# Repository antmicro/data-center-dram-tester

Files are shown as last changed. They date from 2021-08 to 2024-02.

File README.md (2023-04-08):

# Data Center RDIMM DDR4 Tester

Copyright (c) 2021-2023 [Antmicro](https://antmicro.com)



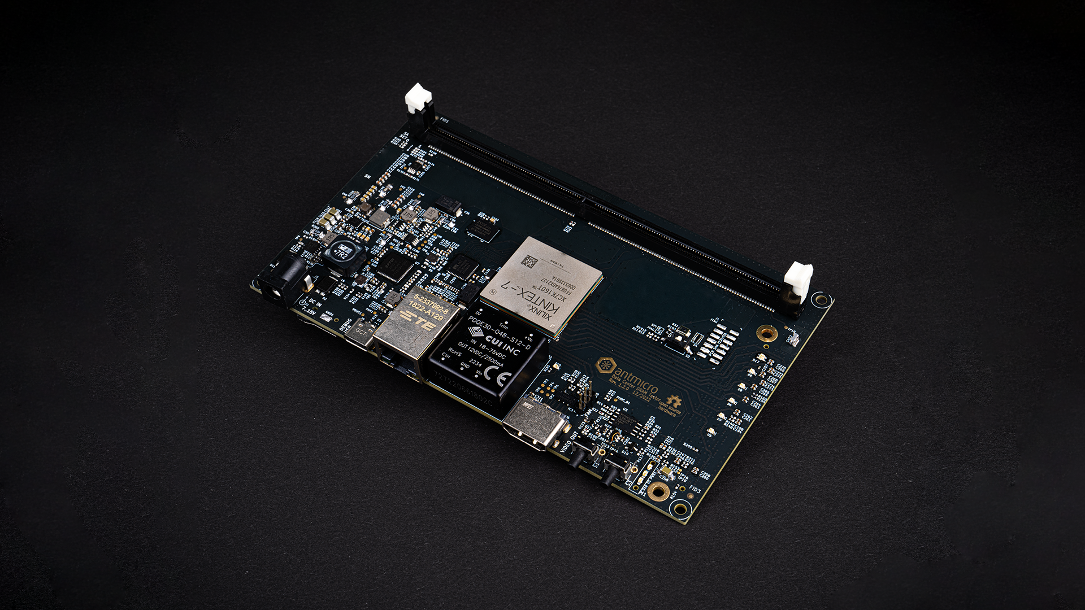
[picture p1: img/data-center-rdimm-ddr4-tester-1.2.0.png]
DDR4 RDIMM tester board


## Overview

This repository contains open hardware KiCad design files for an experimental platform built around the Xilinx Kintex-7 FPGA which can be used to interface with RDIMM DDR4 RAM modules used in data centers.

This hardware platform is used in Antmicro's and Google's [Rowhammer testing framework](https://github.com/antmicro/rowhammer-tester) which can be used to perform (and potentially mitigate) Rowhammer attacks on DRAM memories. You can learn more about Rowhammer and our work towards mitigating it in a Google Open Source blog note [describing a related platform](https://opensource.googleblog.com/2021/11/Open%20source%20DDR%20controller%20framework%20for%20mitigating%20Rowhammer.html).
The usage instructions for this board are also provided in the [Rowhammer testing framework documentation](https://antmicro.github.io/rowhammer-tester/). 

## Repository structure

The main repository directory contains KiCad PCB project files, a LICENSE and README.
The remaining files are stored in the following directories:

* `lib` - contains the component libraries
* `img` - contains graphics for this README

## Key Features

* Kintex-7 FPGA (XC7K160T-FFG676)
* DDR4 RDIMM connector with hotswap
* HDMI output connector
* Ethernet RJ45 connector with 1GbE transciever
* USB-C debug connector with FT4232HQ FTDI USB controller
* JTAG
* microSD card slot
* 16 MBytes S25FL128S QSPI FLASH memory
* S27KL0641 HyperRAM
* External 7-12V DC power input
* PoE++
* Power consumption monitoring
* 5 user LEDs
* Optional FMC HPC expansion connector

## Block diagram

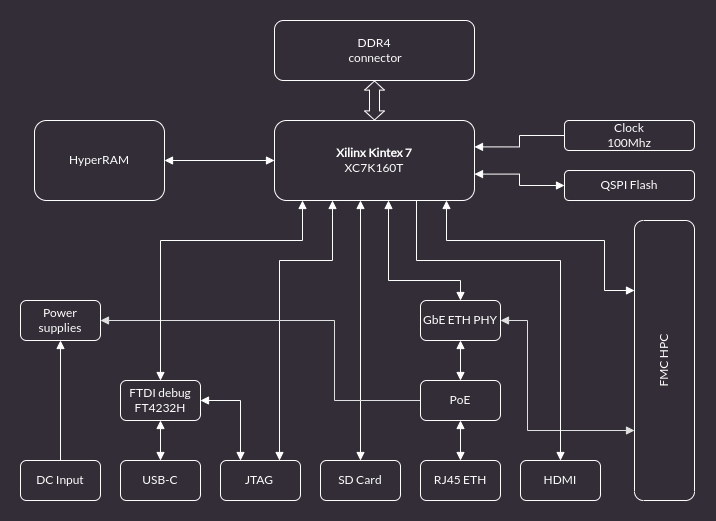
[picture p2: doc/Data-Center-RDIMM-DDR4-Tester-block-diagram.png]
Data Center RDIMM DDR4 Tester board diagram


## License

This project is published under the [Apache-2.0](LICENSE) license.

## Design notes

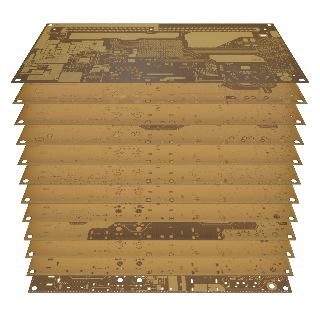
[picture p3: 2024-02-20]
assets/previews/layer1_thumbnail.webp

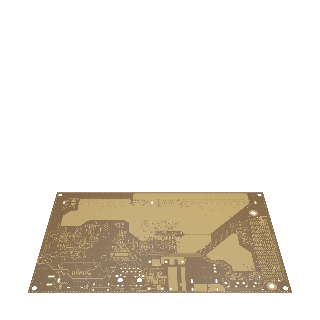
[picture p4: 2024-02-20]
assets/previews/layer12_thumbnail.png

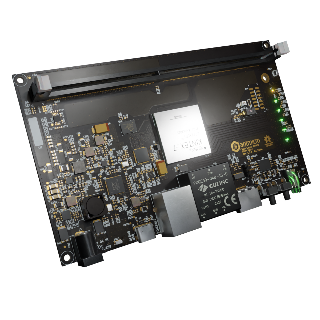
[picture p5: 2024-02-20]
assets/previews/leftT_thumbnail.png

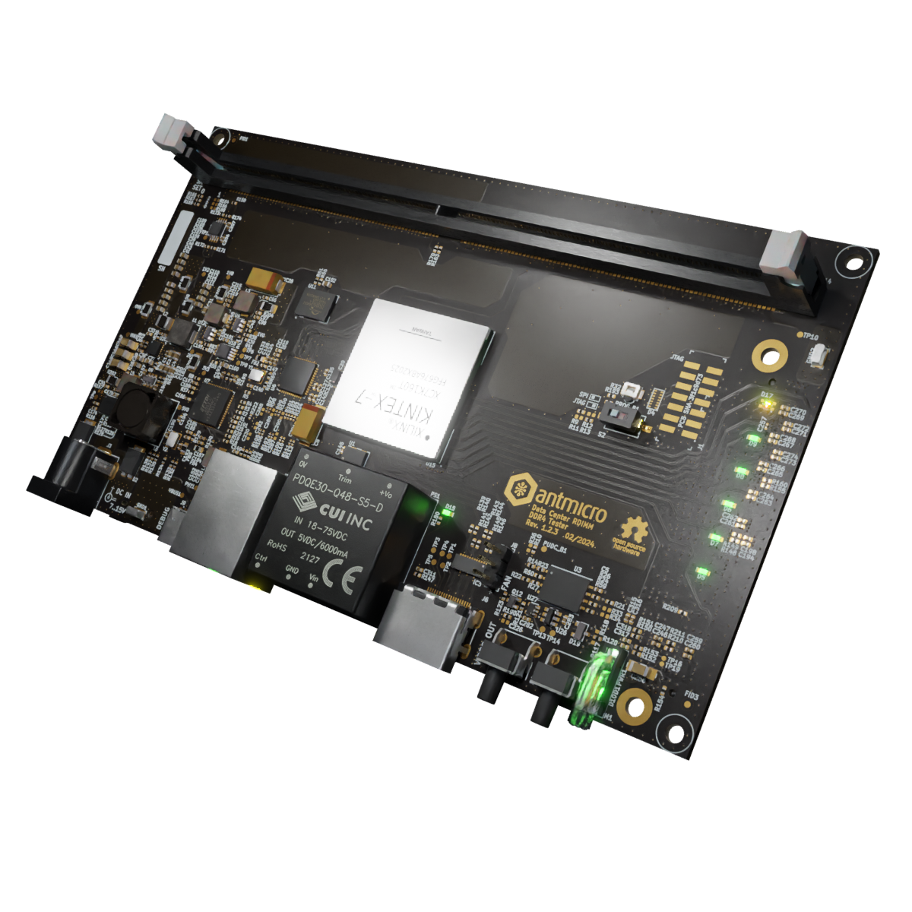
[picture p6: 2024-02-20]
assets/previews/rightT.webp

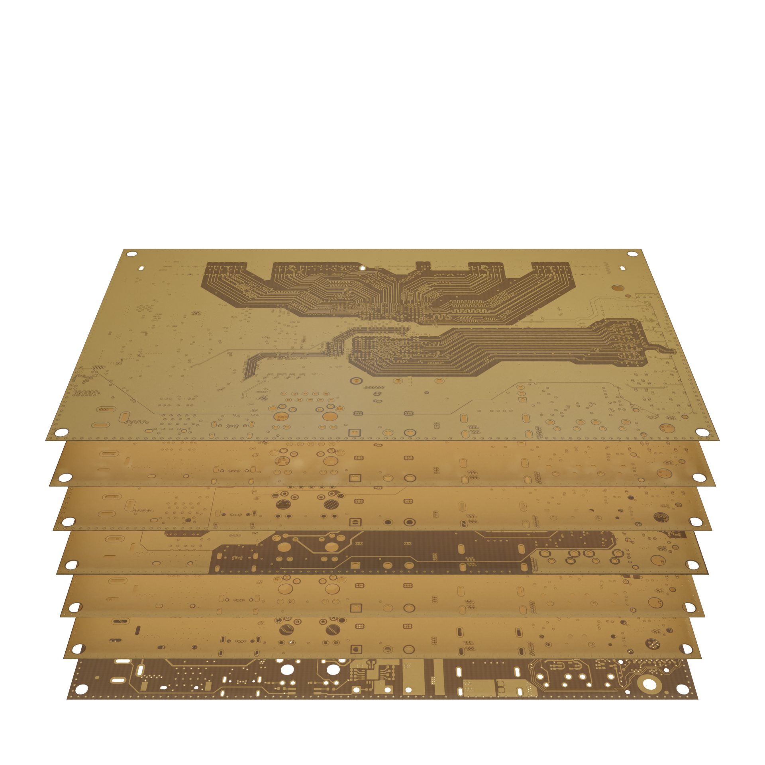
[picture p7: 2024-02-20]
assets/previews/layer6.png

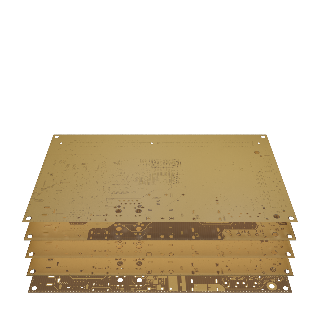
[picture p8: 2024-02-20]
assets/previews/layer8_thumbnail.png

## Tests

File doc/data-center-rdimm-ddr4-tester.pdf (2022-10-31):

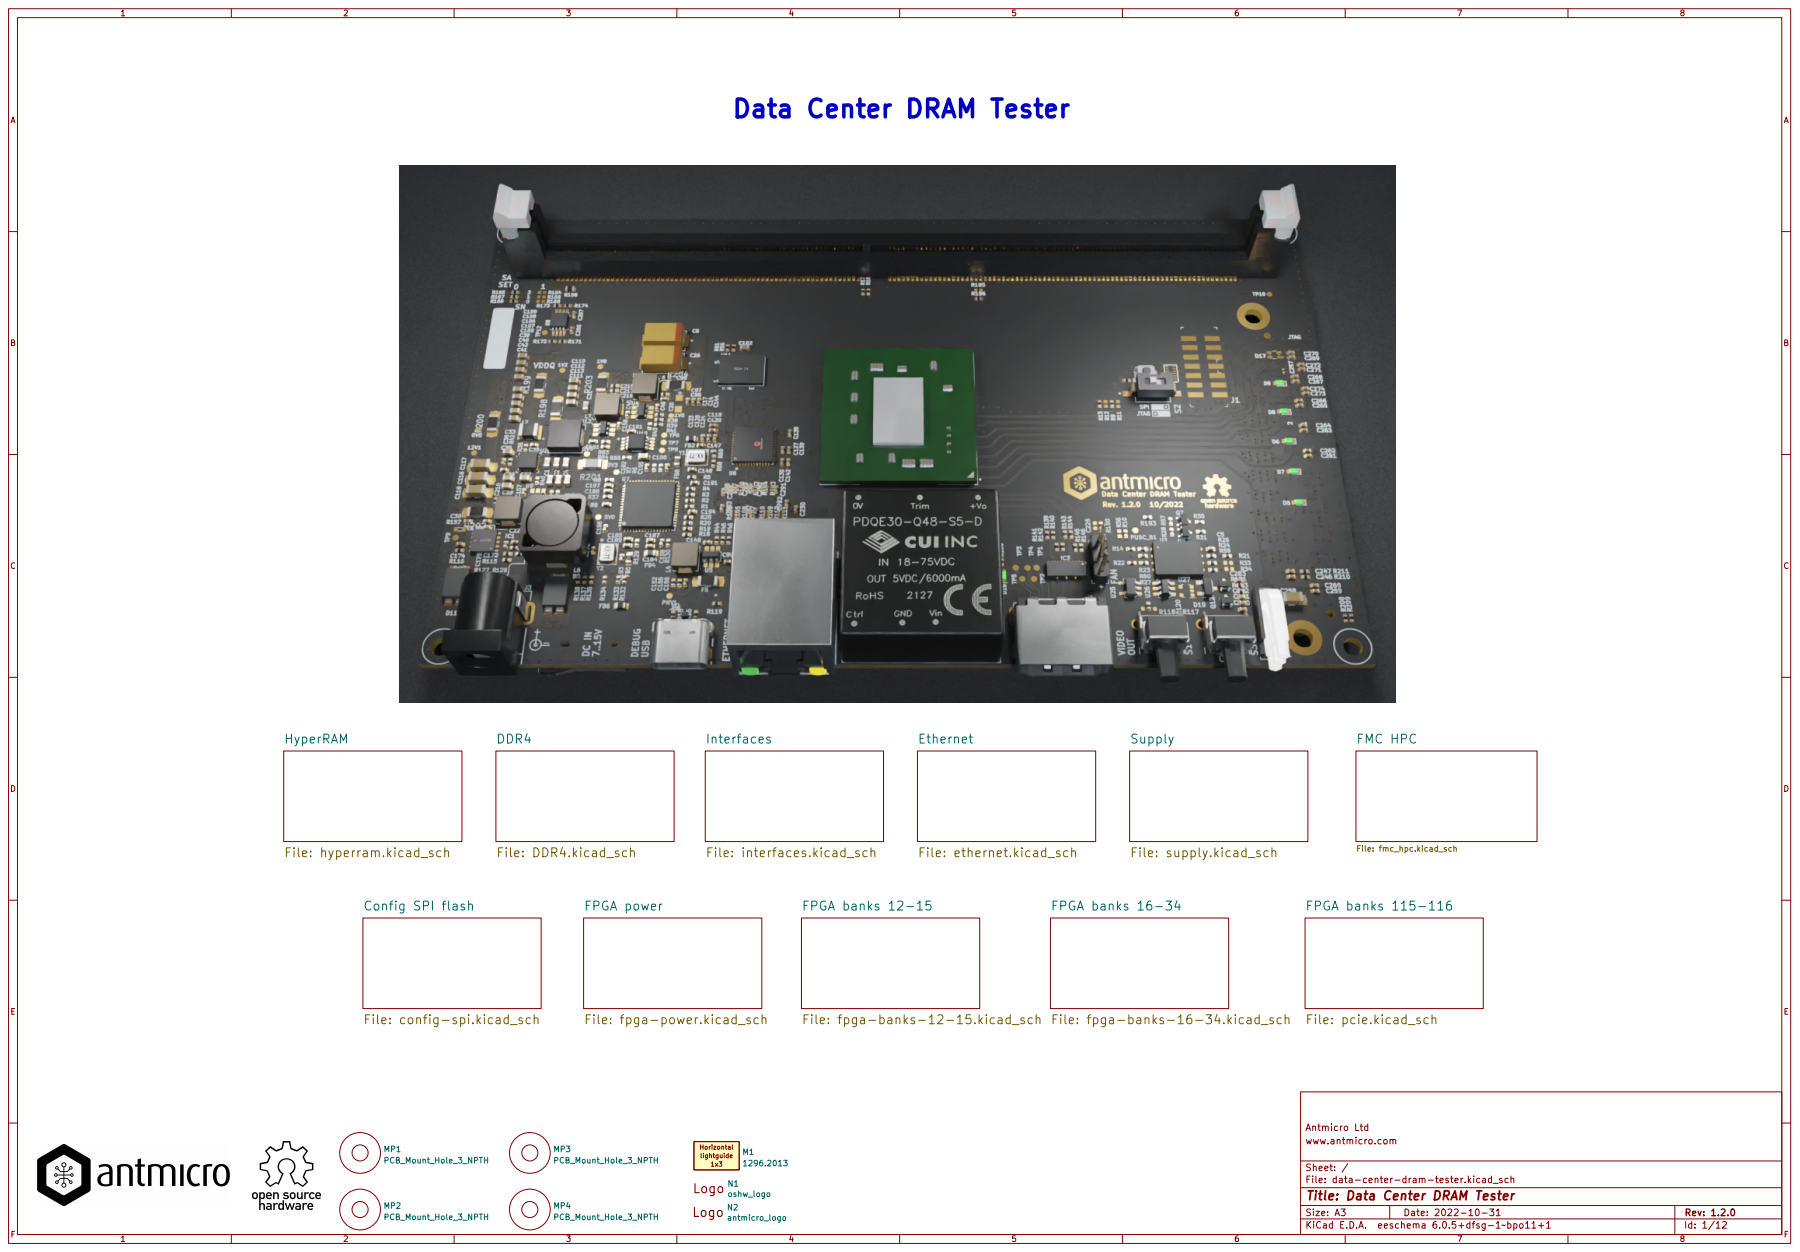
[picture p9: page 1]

File: data-center-dram-tester.kicad_sch Sheet: / www.antmicro.com

Id: 1/12 Title: Data Center DRAM Tester

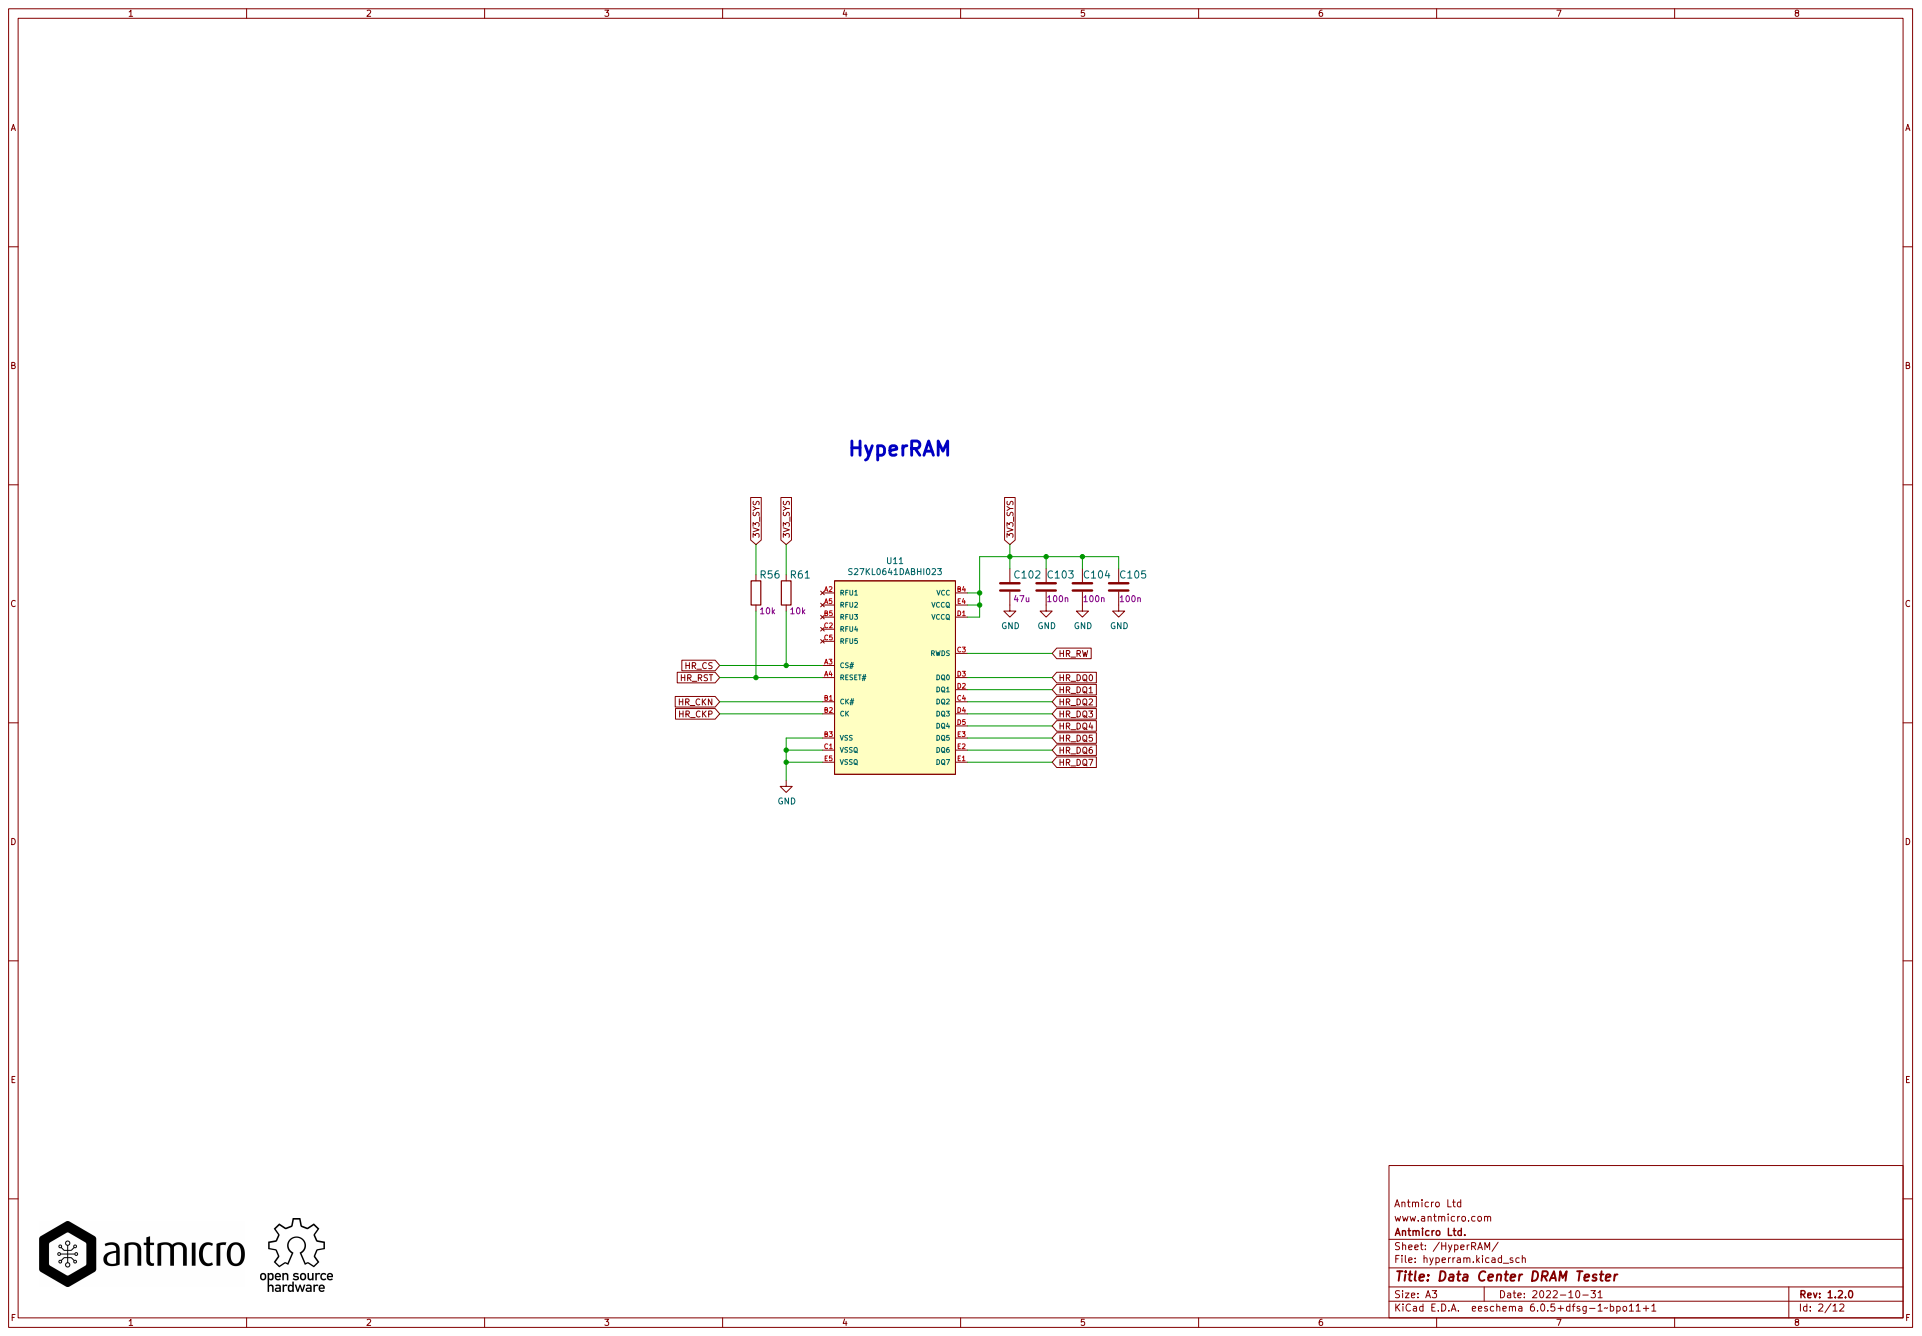
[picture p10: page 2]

Antmicro Ltd
Sheet: /HyperRAM/ Antmicro Ltd. www.antmicro.com

File: hyperram.kicad_sch
Id: 2/12 Title: Data Center DRAM Tester

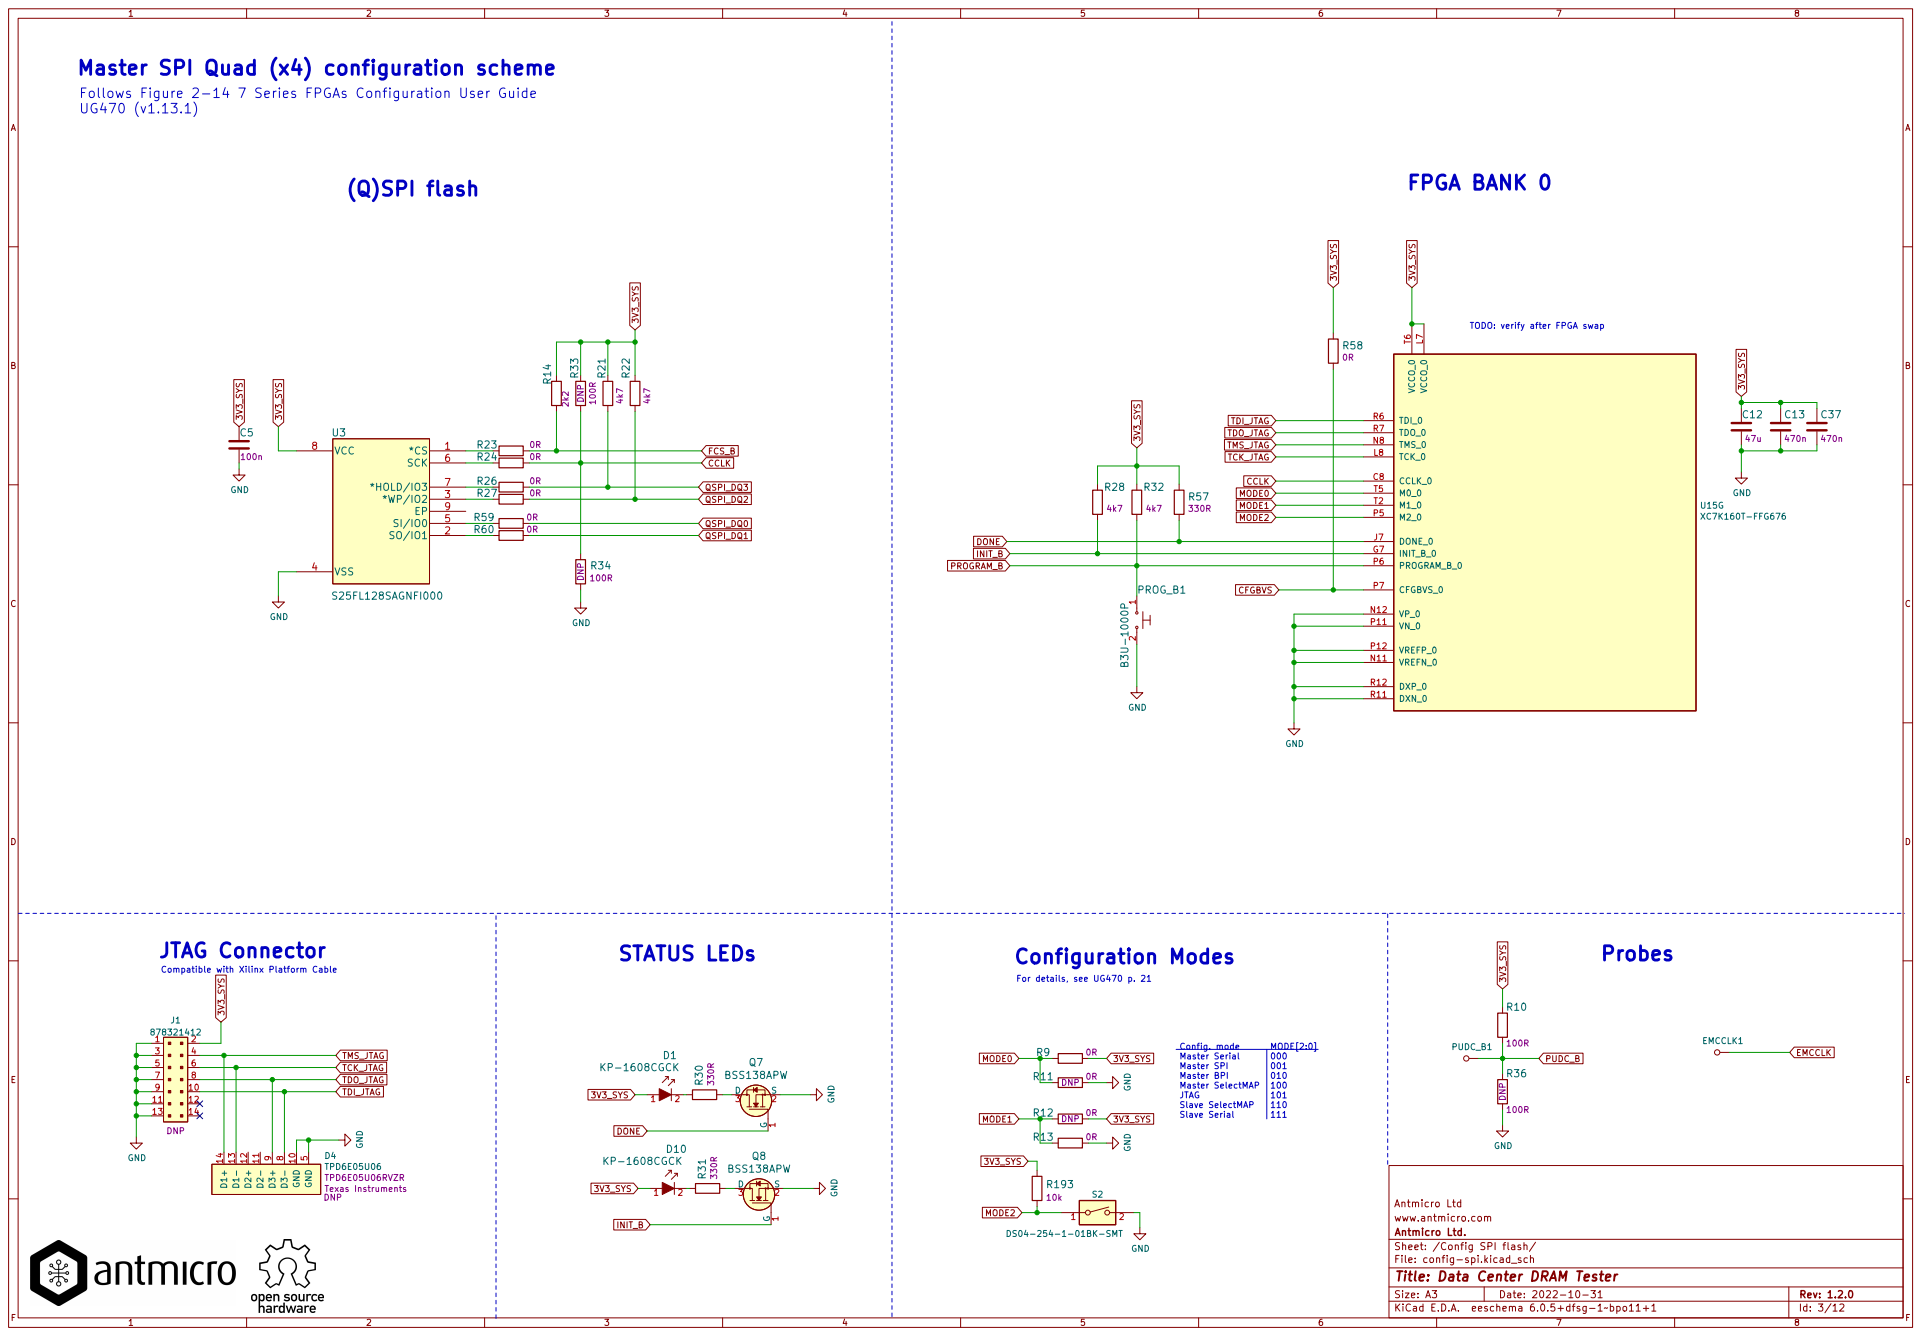
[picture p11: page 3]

Master SPI Quad (x4) configuration scheme
Follows Figure 2-14 7 Series FPGAs Configuration User Guide

TODO: verify after FPGA swap

Compatible with Xilinx Platform Cable
878321412 DNP

Config. mode Master Serial Master SPI Master BPI Master SelectMAP

9 | 10

Sheet: /Config SPI flash/ Antmicro Ltd. www.antmicro.com

File: config-spi.kicad_sch
Id: 3/12 Title: Data Center DRAM Tester

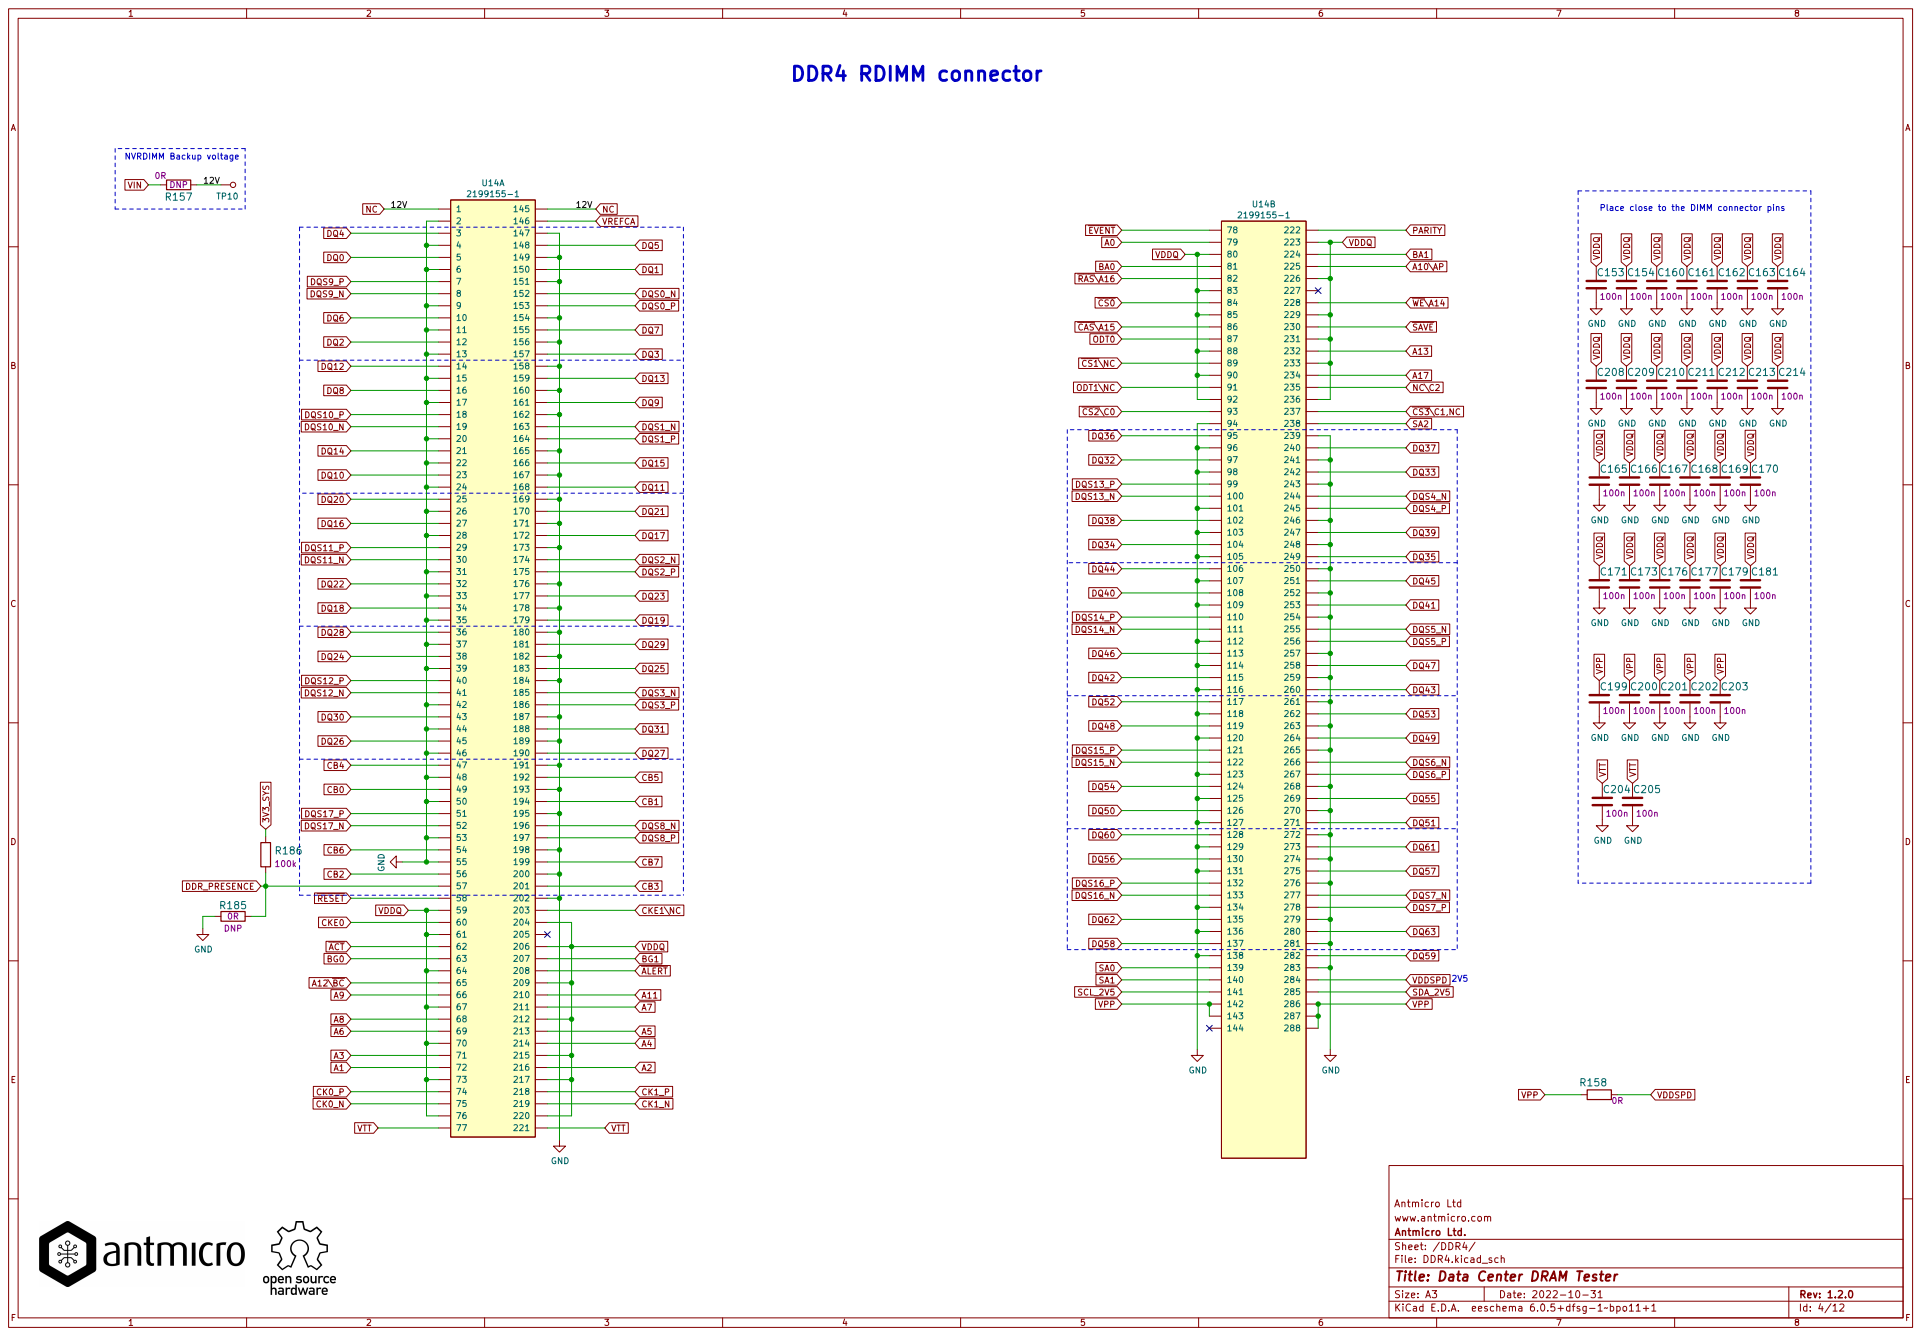
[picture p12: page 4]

DQ20 | | 7789 U14A 697 25 169 26 170 27 171 28 172 173 30 174 31 175 32 176 33 177 34 178 35 179 | DQS2_N

Place close to the DIMM connector pins

199 2 394 495 596 14 158 15 159 16 160 17 161 18 162 19 163 20 164 21 165 22 166 23 167 24 168 | DQ7 DQ5 DQS0_P DQ14 DQS8_N DQS1_N

DQS12_N | | 36 180 37 181 38 182 183 40 184 41 185 42 186 43 187 44 188 45 189 46 190 | DQS3_N

117 261 118 262 119 263 120 264 121 265 122 266 123 267 124 268 125 269 126 270 127 271 | DQ47 DQS6_P DQS6_N

128 272 129 273 130 274 131 275 132 276 133 277 134 278 135 279 136 280 137 281 | DQ61 SCL_2V5 DQS16_N DQ57 SA1 DQS7_N

Antmicro Ltd
File: DDR4.kicad_sch Sheet: /DDR4/ Antmicro Ltd. www.antmicro.com

Id: 4/12 Title: Data Center DRAM Tester

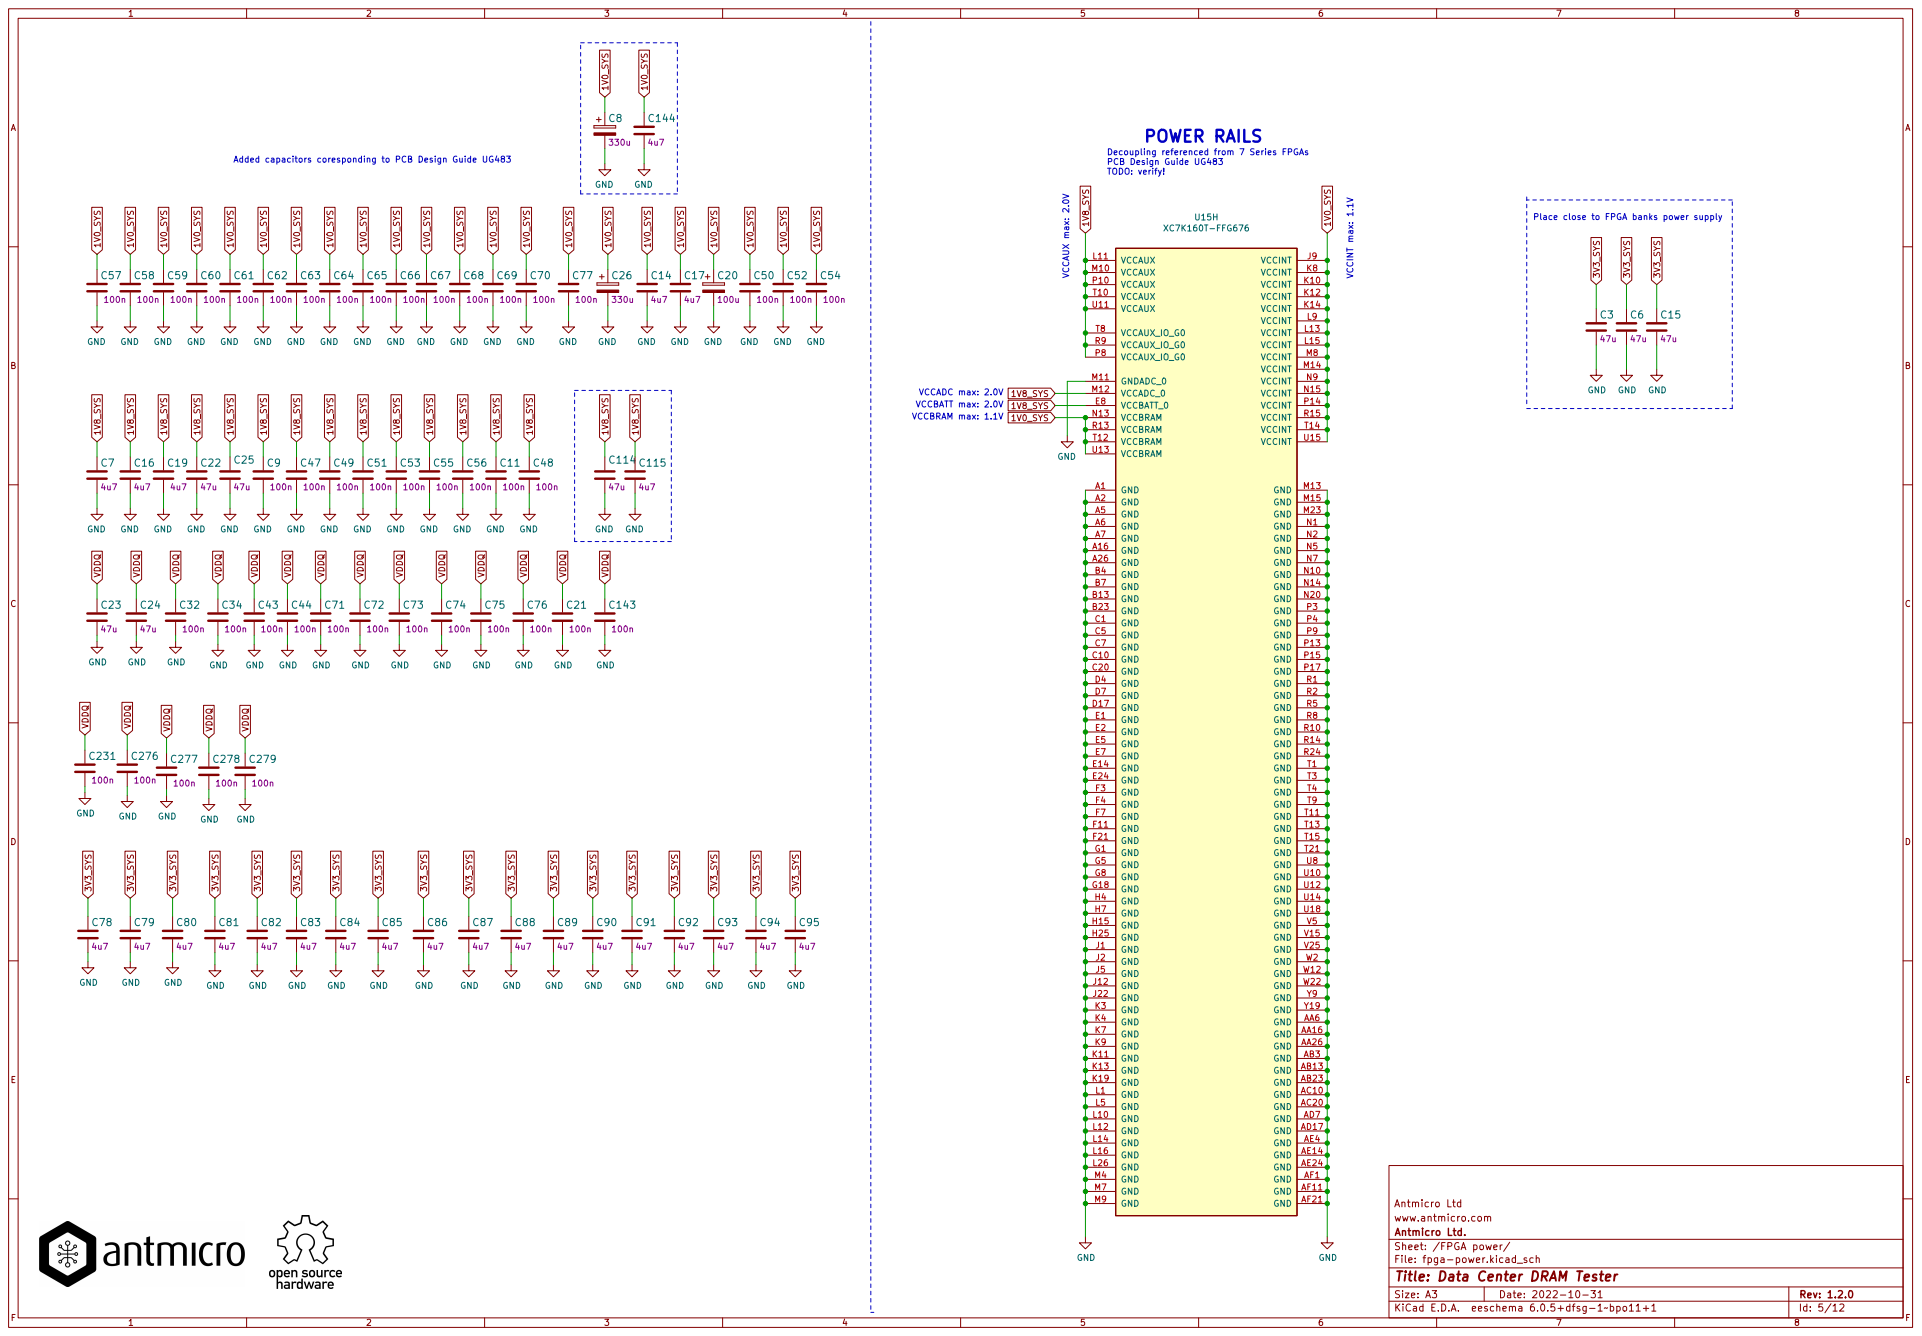
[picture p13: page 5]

Added capacitors coresponding to PCB Design Guide UG483

TODO: verify! VCCAUX max: 2.0V

Antmicro Ltd
Sheet: /FPGA power/ Antmicro Ltd. www.antmicro.com

File: fpga-power.kicad_sch
Id: 5/12 Title: Data Center DRAM Tester

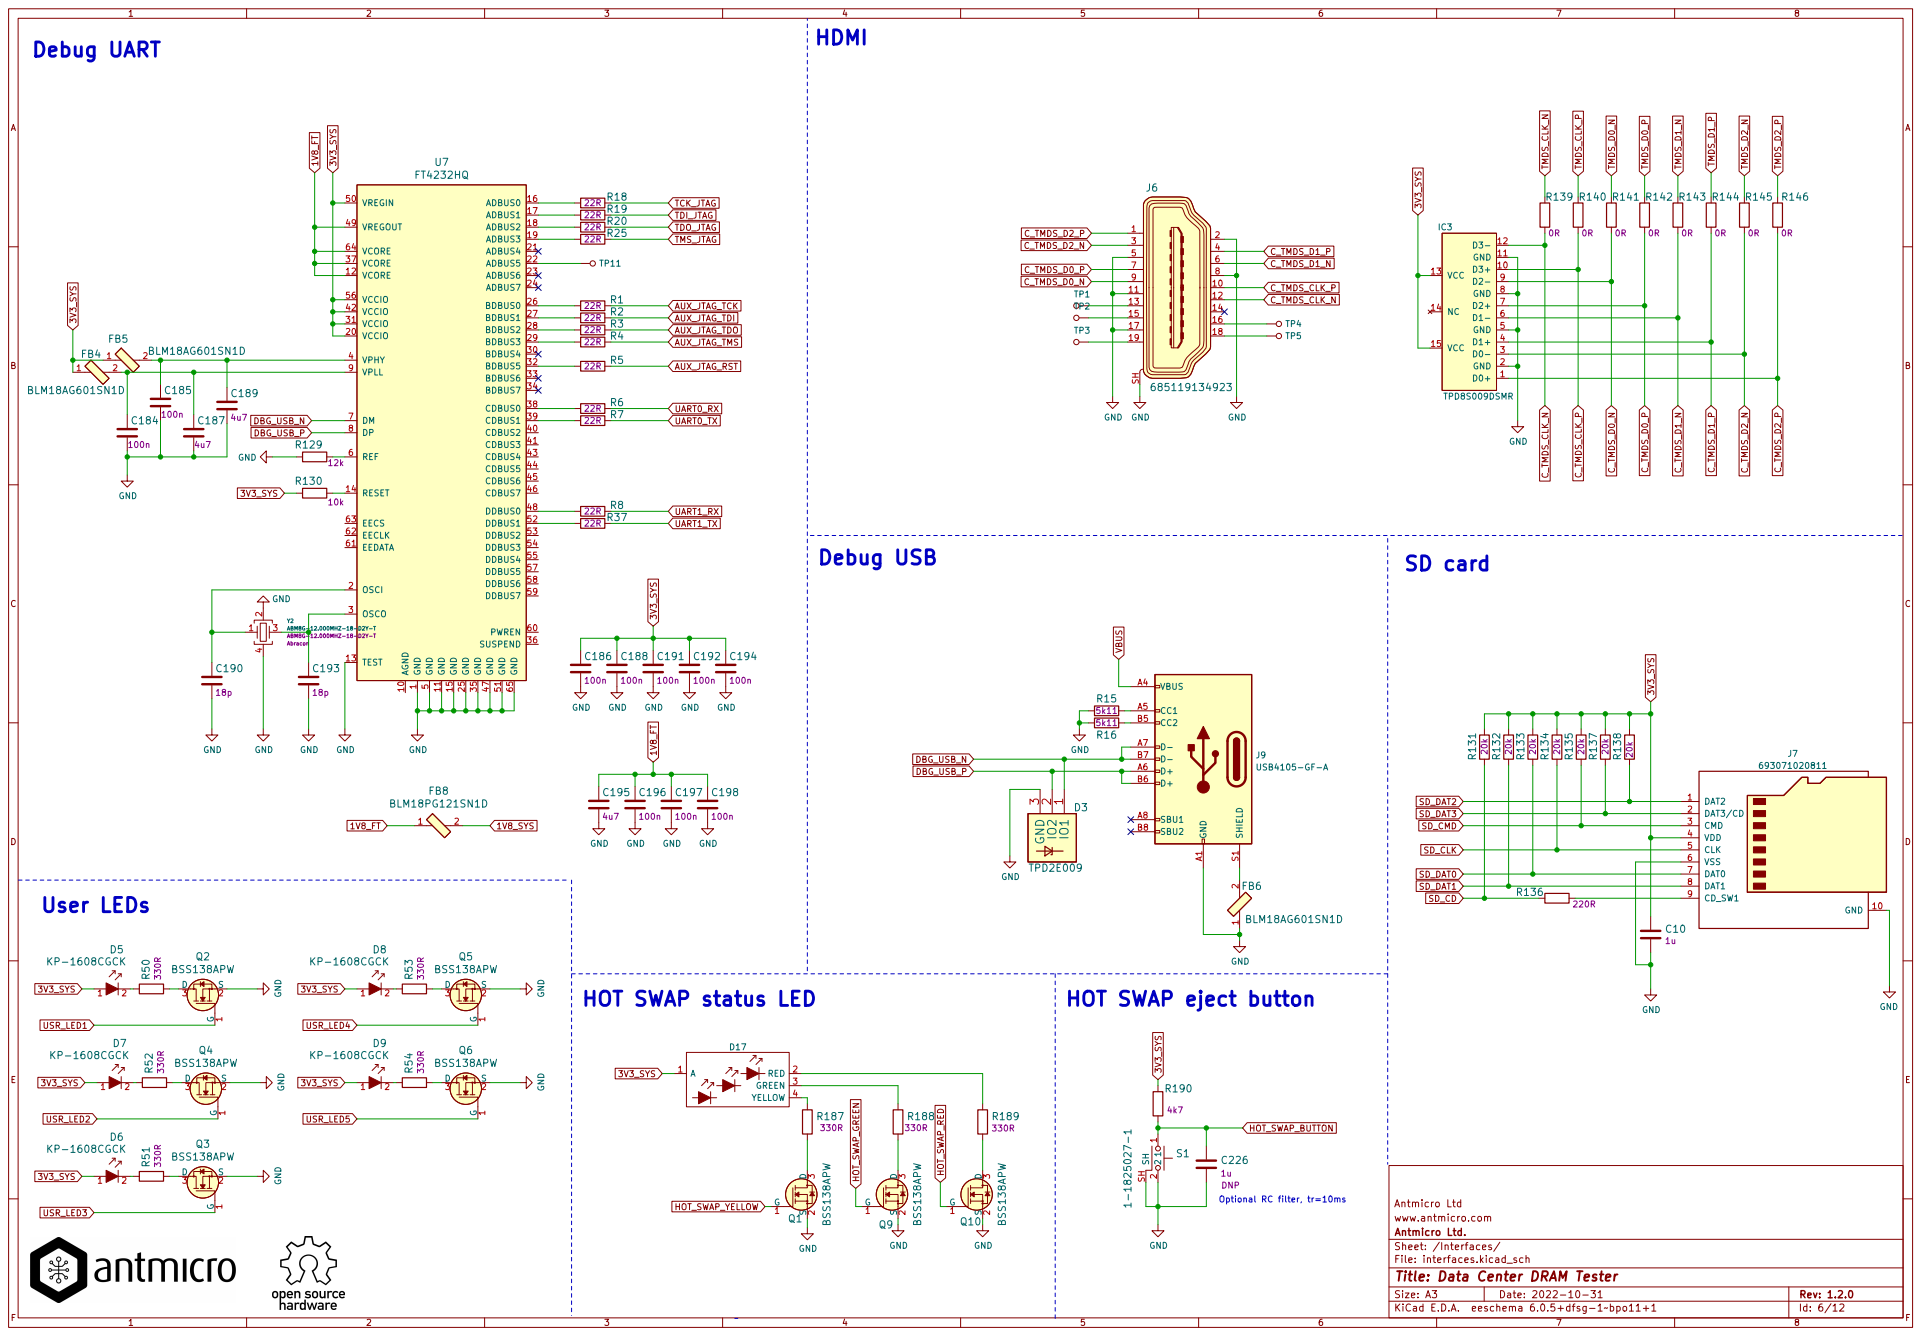
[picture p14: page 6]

5 VREGIN 50 GND 51 DDBUS1 52 DDBUS2 53 DDBUS3 54 DDBUS4 55 VCCIO 56 DDBUS5 57 DDBUS6 58 DDBUS7 59 REF 6 PWREN 60 EEDATA 61 EECLK 62 EECS 63 VCORE 64 GND 65 DM 7 DP 8 VPLL 9 U7 FT4232HQ

1 AGND 10 GND 11 VCORE 12 TEST 13 RESET 14 GND 15 ADBUS0 16 ADBUS1 17 ADBUS2 18 ADBUS3 19 OSCI 2 VCCIO 20 ADBUS4 21 ADBUS5 22 ADBUS6 23 ADBUS7 24 GND 25 BDBUS0 26 BDBUS1 27 BDBUS2 28 BDBUS3 29 OSCO 3 BDBUS4 30 VCCIO 31 BDBUS5 32 BDBUS6 33 BDBUS7 34 GND 35 SUSPEND 36 VCORE 37 CDBUS0 38 CDBUS1 39 VPHY 4 CDBUS2 40 CDBUS3 41 VCCIO 42 CDBUS4 43 CDBUS5 44 CDBUS6 45 CDBUS7 46 GND 47 DDBUS0 48 VREGOUT 49 GND

HOT SWAP status LED

HOT SWAP eject button

Optional RC filter, tr=10ms

File: interfaces.kicad_sch Sheet: /Interfaces/ Antmicro Ltd. www.antmicro.com

Id: 6/12 Title: Data Center DRAM Tester

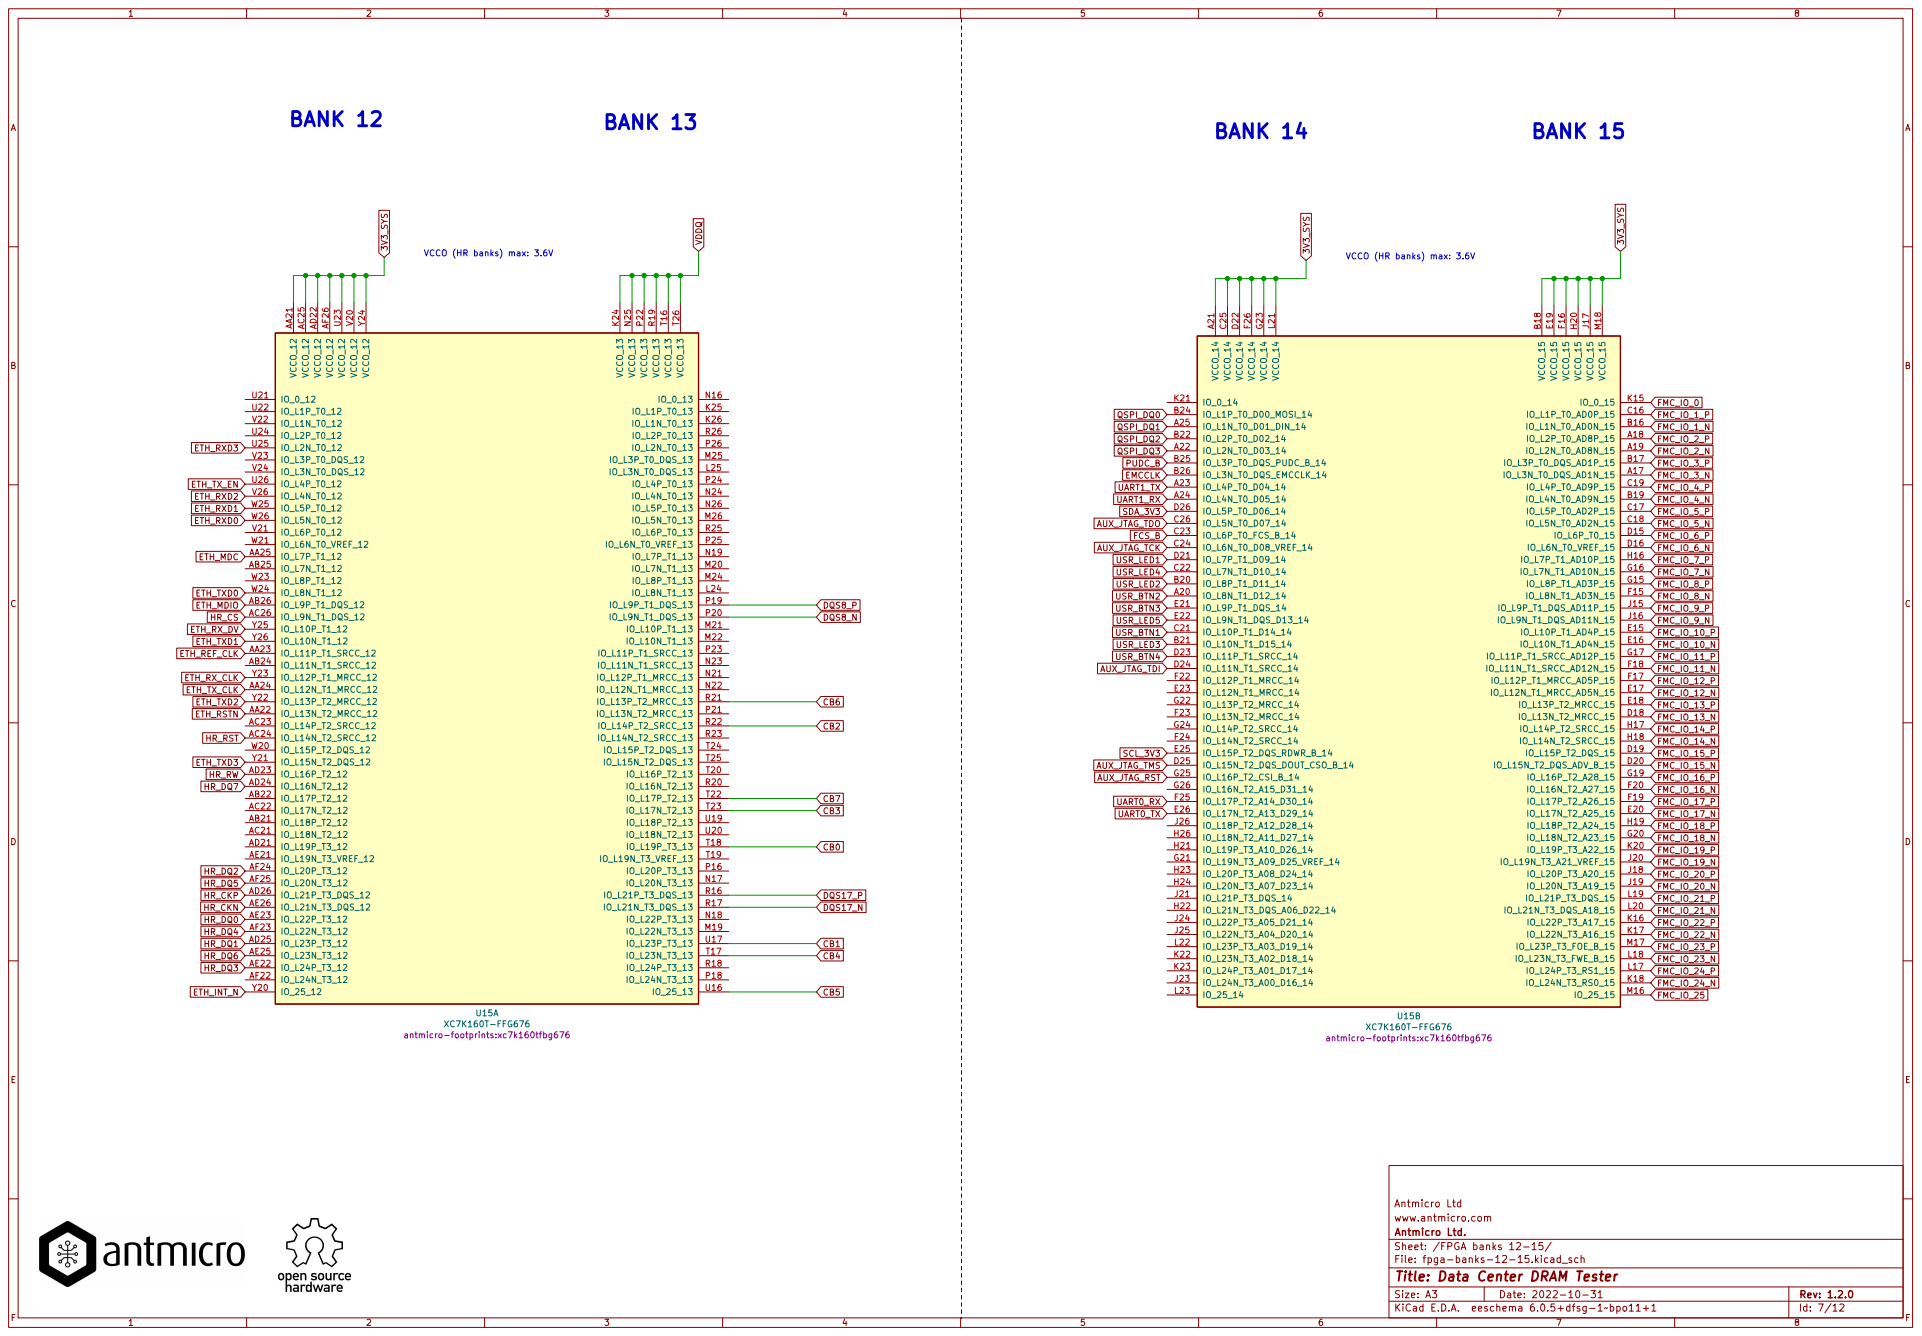
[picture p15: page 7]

VCCO (HR banks) max: 3.6V

Antmicro Ltd
File: fpga-banks-12-15.kicad_sch Sheet: /FPGA banks 12-15/ Antmicro Ltd. www.antmicro.com

Id: 7/12 Title: Data Center DRAM Tester

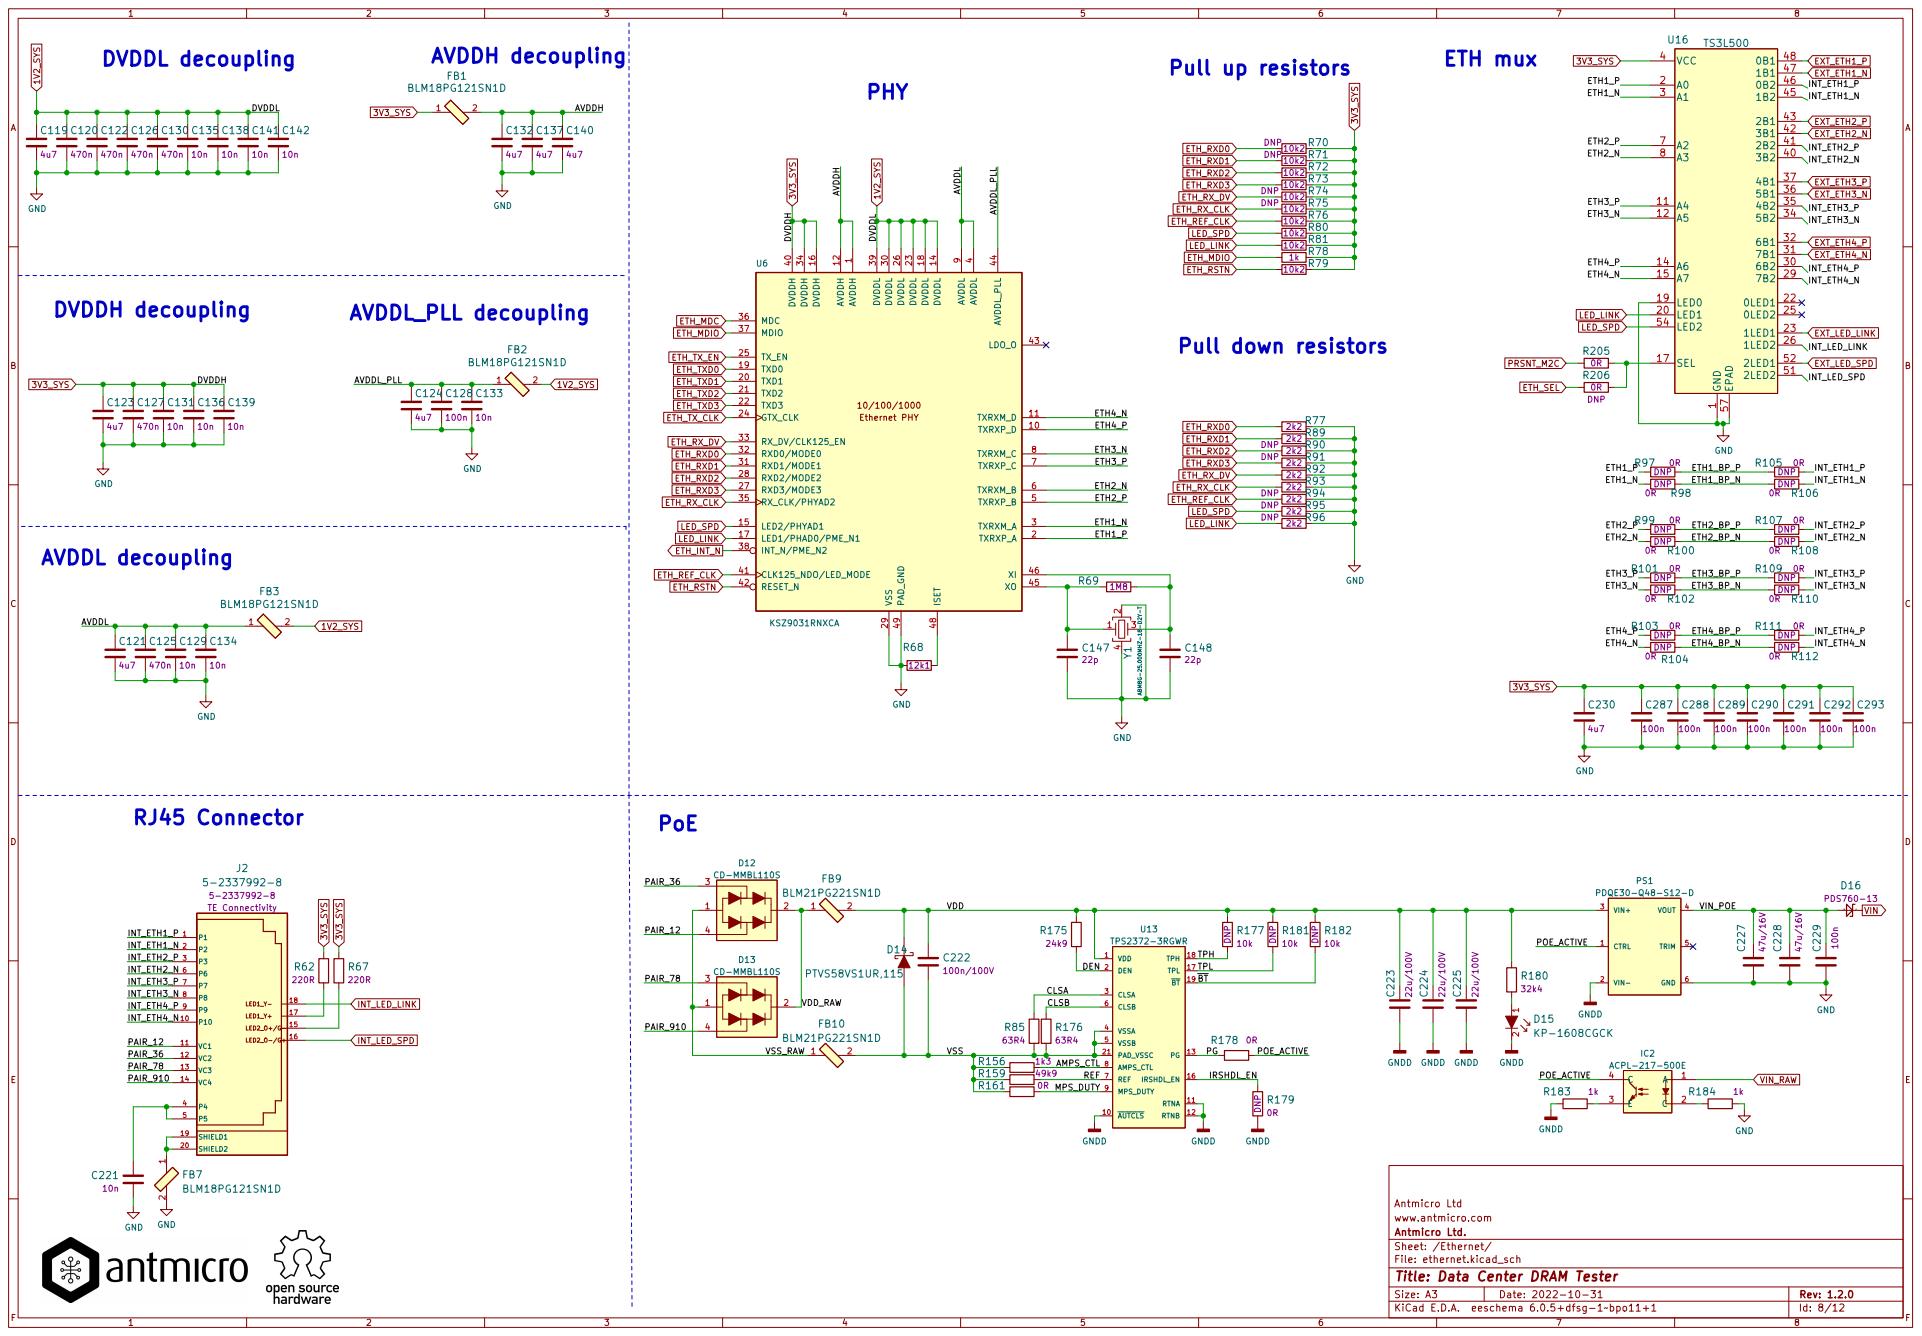
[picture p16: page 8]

Antmicro Ltd
File: ethernet.kicad_sch Sheet: /Ethernet/ Antmicro Ltd. www.antmicro.com

Id: 8/12 Title: Data Center DRAM Tester

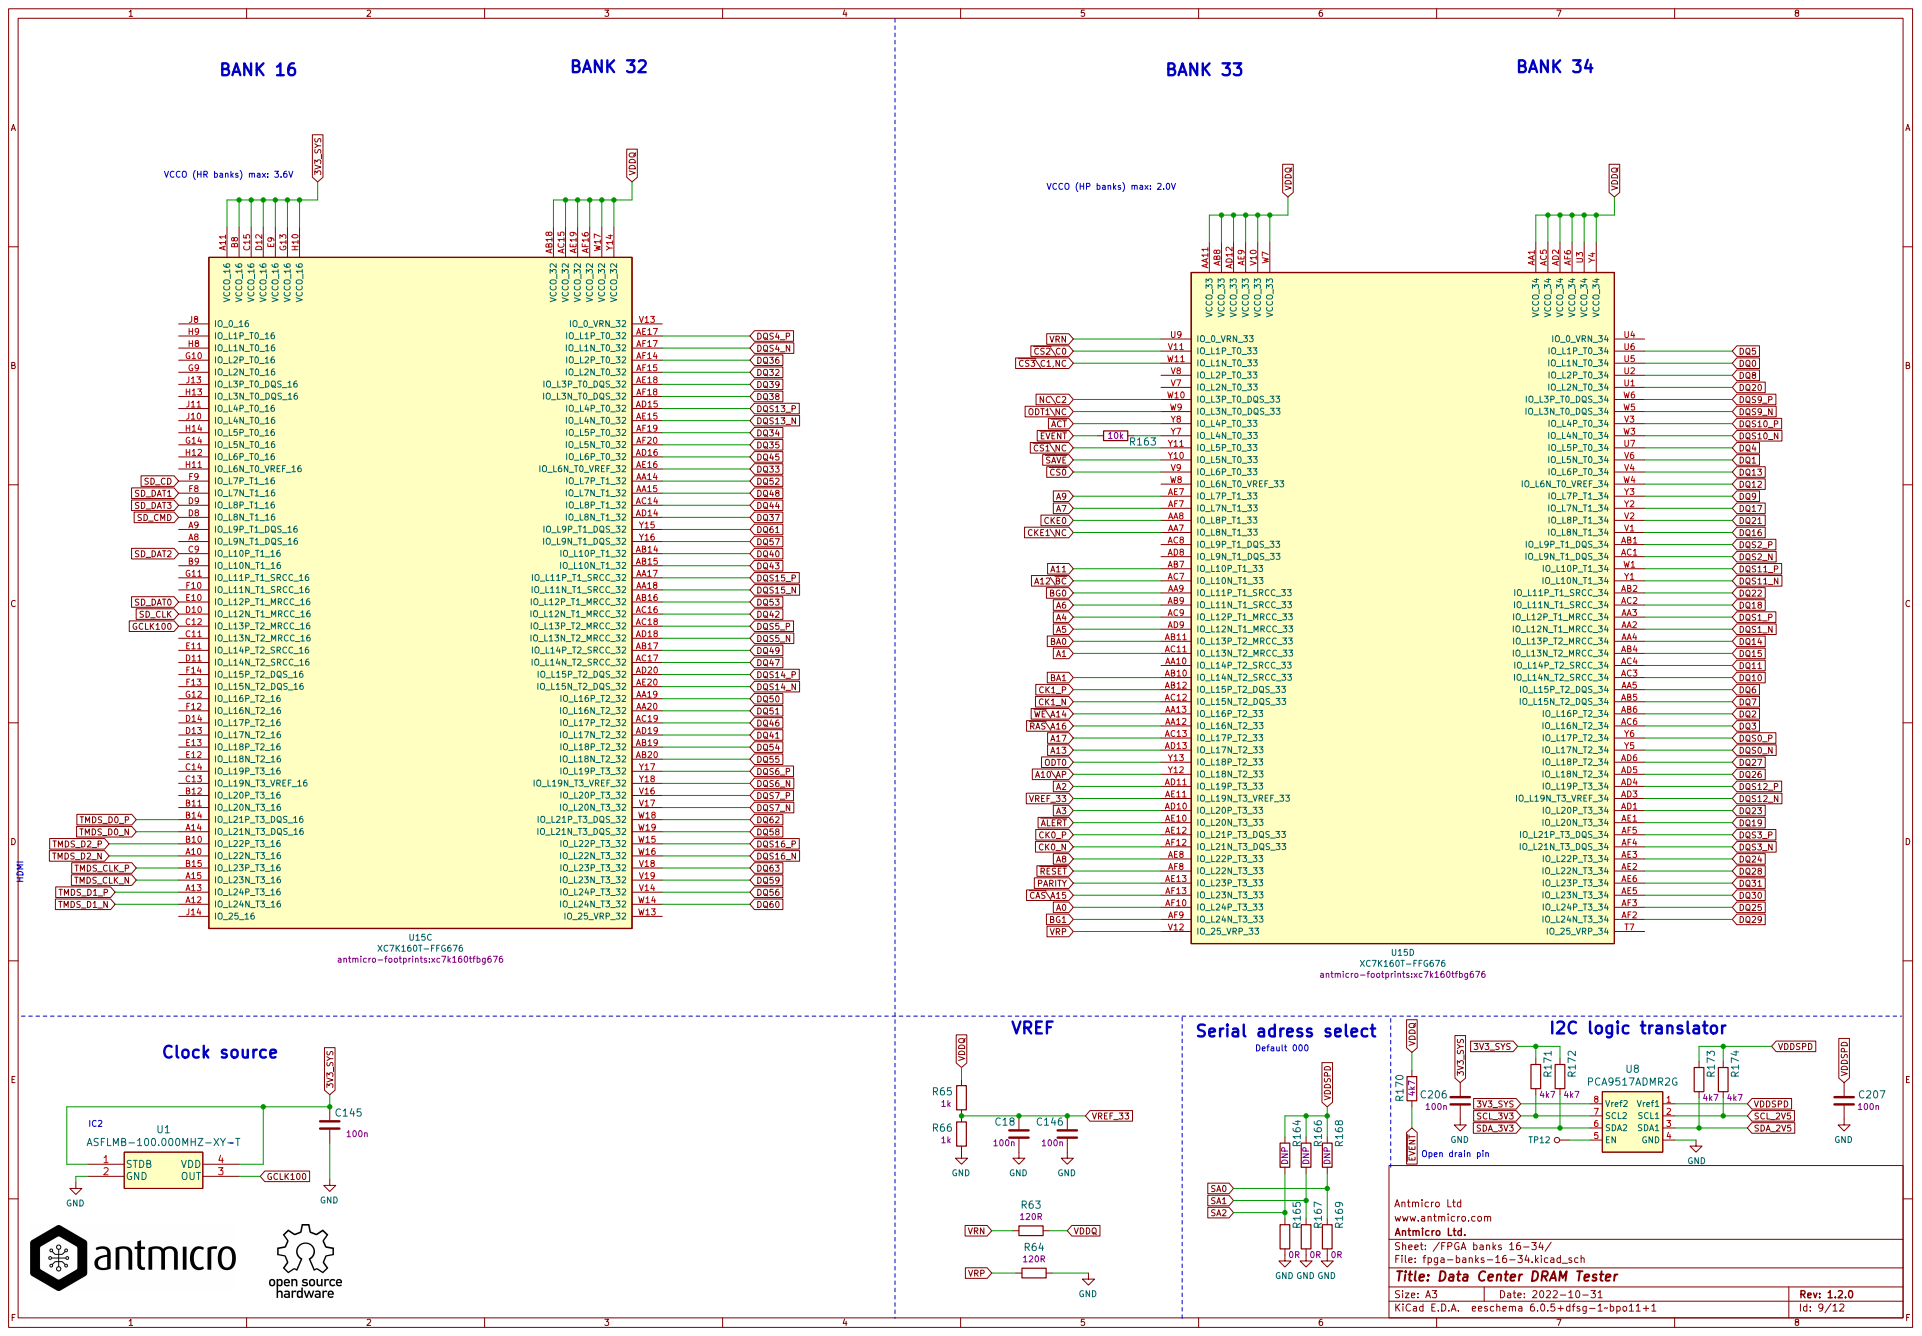
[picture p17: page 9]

VCCO (HR banks) max: 3.6V

VCCO (HP banks) max: 2.0V

File: fpga-banks-16-34.kicad_sch Sheet: /FPGA banks 16-34/ Antmicro Ltd. www.antmicro.com

Id: 9/12 Title: Data Center DRAM Tester

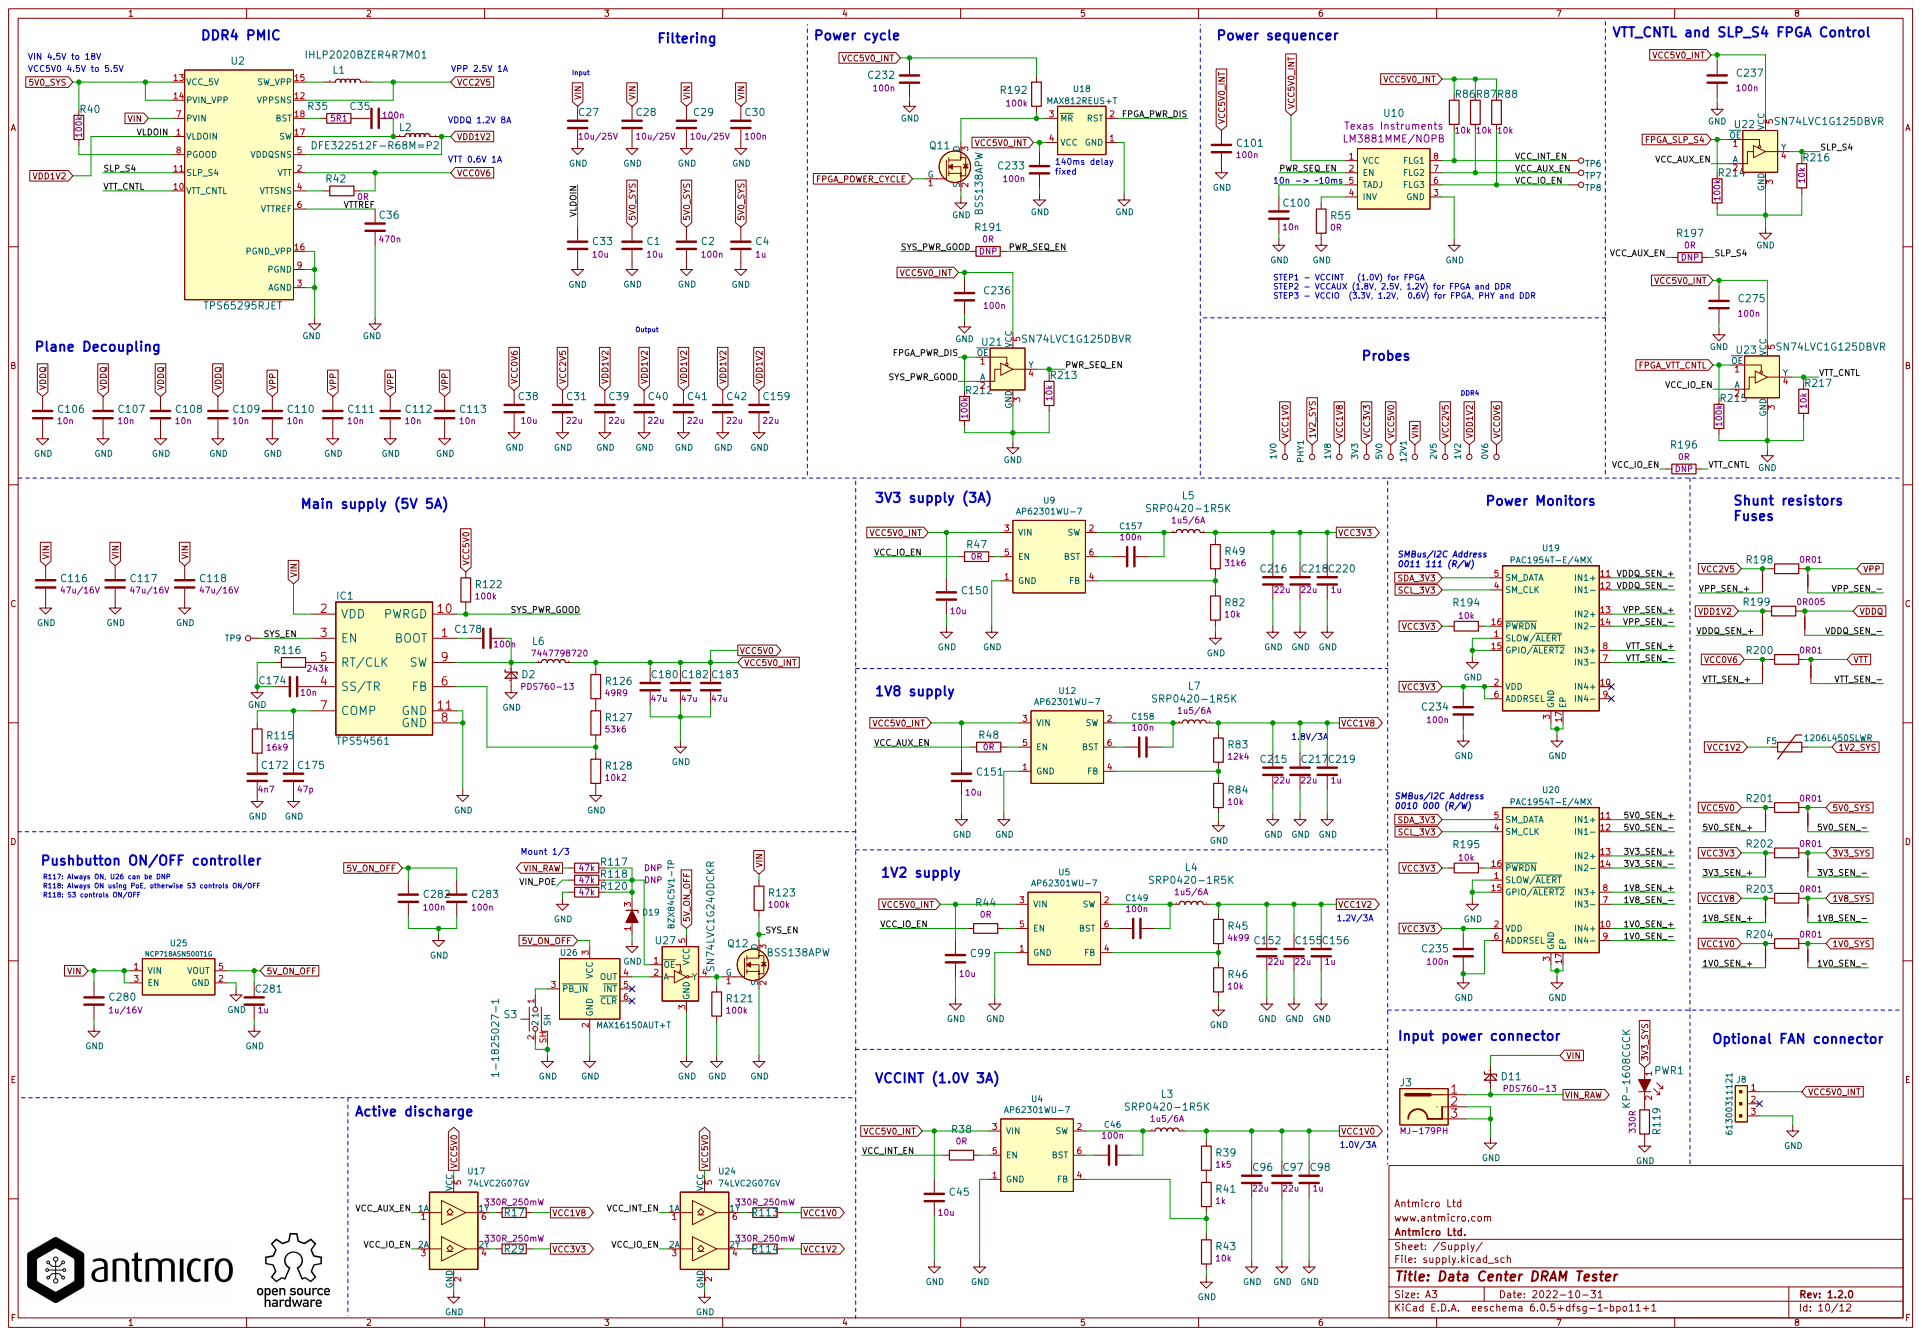
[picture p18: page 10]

STEP1 - VCCINT (1.0V) for FPGA
STEP2 - VCCAUX (1.8V, 2.5V, 1.2V) for FPGA and DDR
STEP3 - VCCIO (3.3V, 1.2V, 0.6V) for FPGA, PHY and DDR

Pushbutton ON/OFF controller

Input power connector Mount 1/3

1 3 D19 BZX84C5V1-TP R118 47k DNP R120 47k GND GND C282

R118: Always ON using PoE, otherwise S3 controls ON/OFF R117: Always ON, U26 can be DNP

Antmicro Ltd
Sheet: /Supply/ Antmicro Ltd. www.antmicro.com

File: supply.kicad_sch
Id: 10/12 Title: Data Center DRAM Tester


Trace length from the resistor pins to the FPGA pins MGTRREF and MGTAVTTRCAL must be equal in length.

File: pcie.kicad_sch Sheet: /FPGA banks 115-116/ www.antmicro.com

Id: 11/12 Title: Data Center DRAM Tester


Place close to connector Resistors needed to comply with standard HCSL PCIe clock.
Route REFCLK as 50 Ohm SE (or 100 Ohm diff)

Antmicro Ltd
File: fmc_hpc.kicad_sch Sheet: /FMC HPC/ www.antmicro.com

Id: 12/12 Title: Data Center DRAM Tester

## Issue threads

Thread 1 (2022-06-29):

can't find the product named XC7K100T where...

jihoon-you, 2022-06-29:
i try to make the dram tester. but i can find the product XC7K100T at Xilinx homepage.
Where can i find it??

pkatarzynski, 2022-06-30:
Hi jihoon-you

The correct part number for the FPGA used in the project in is XC7K160T-FFG676. This is mentioned in the the KiCAD design files and can be generated into a BOM list. We have used a XC7K160T-2FBG676C version for prototyping.

So, the FPGA part number mentioned in README  was incorrect. I have fixed that. Thanks for spotting this.

Closed 2022-06-30.

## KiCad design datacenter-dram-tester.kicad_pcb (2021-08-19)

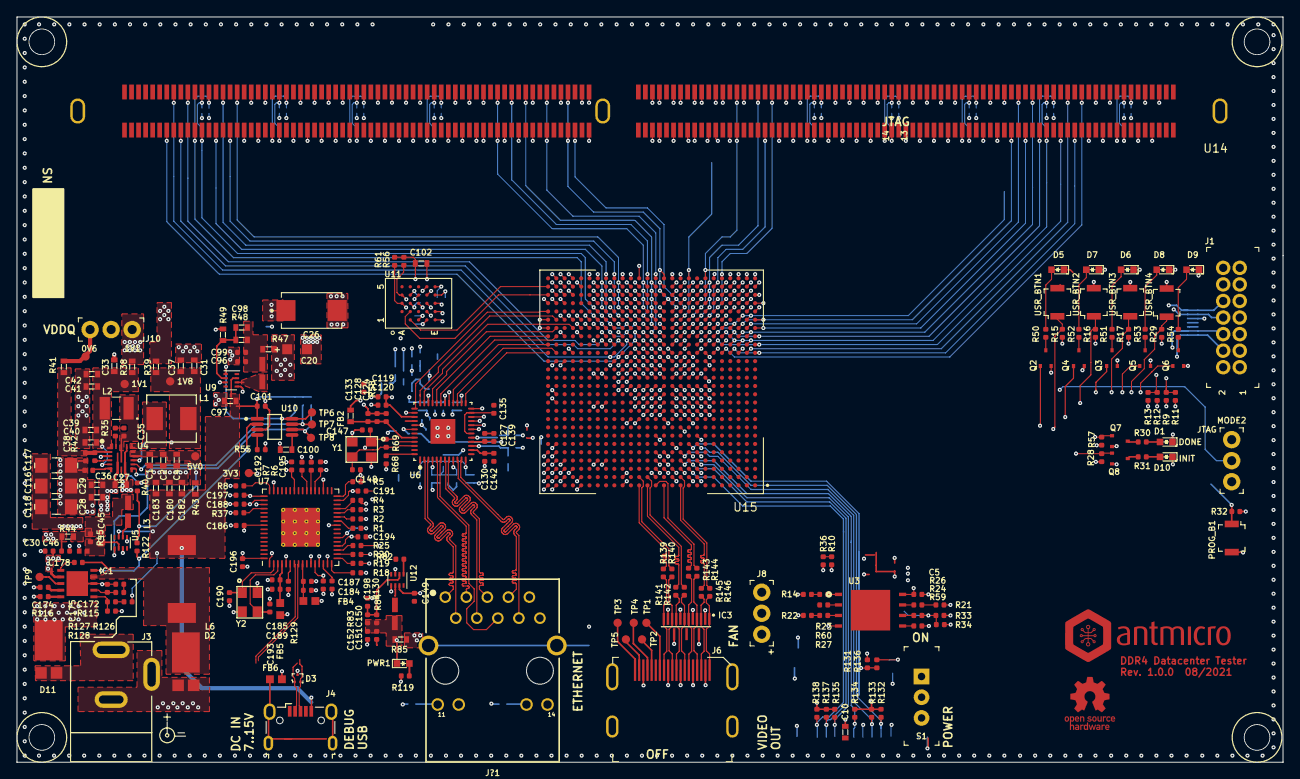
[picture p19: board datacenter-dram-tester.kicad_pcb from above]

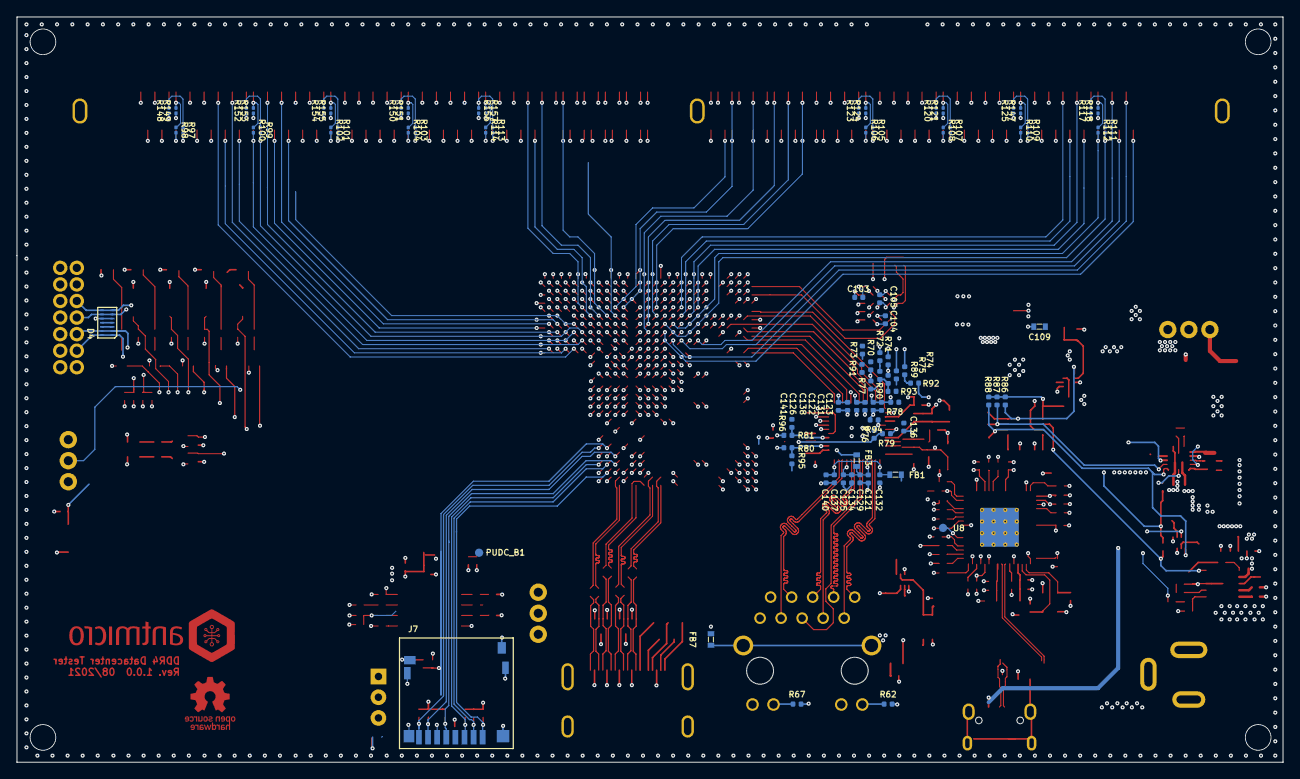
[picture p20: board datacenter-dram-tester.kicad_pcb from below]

Board: 10 copper layers, 152.9 x 90.0 mm, 322 parts (86 on the bottom side), 373 nets.

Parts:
0V6, 1V1, 1V8, 3V3, 5V0: TP_SMD1MM; Testpoint_smd_1mm
C1, C33: C_10u_0603; 0603-cap
C2: C_100n_0603; 0603-cap
C4, C10: C_1u_0603; 0603-cap
C5, C35, C101, C103, C104, C105, C178, C184, C185, C186, C188, C191, C192, C194, C196, C197, C198: C_100n_0402_6V3; 0402-cap
C20: C_100u_KEMET_A; KEMET_A
C26: C_330u_KEMET_D; KEMET_D
C27, C28, C29: C_10u_25V_0603; 0603-cap
C30: C_100n_0402_16V; 0402-cap
C31, C37, C39, C40, C41, C42: C_22u_0603; 0603-cap
C36, C120, C122, C125, C126, C127: C_470n_0402; 0402-cap
C38, C46, C96, C99, C149, C151, C152: C_10u_0402; 0402-cap
C45, C98: C_120p_0603; 0603-cap
C97: C_4u7_0603; 0603-cap
C100, C109: C_10n_0603; 0603-cap
C102, C180, C182, C183: C_47u_0603; 0603-cap
C116, C117, C118: C_47u_16V_1206; 1206-cap
C119, C121, C123, C124, C132, C187, C189, C195: C_4u7_0402; 0402-cap
C128: C_100n_0402; 0402-cap
C129, C130, C131, C133, C134, C135, C136, C137, C138, C139, C140, C141, C142, C174: C_10n_0402; 0402-cap
C147, C148: C_22p_0402; 0402-cap
C150: C_120p_0402; 0402-cap
C172: C_4n7_0402; 0402-cap
C175: C_47p_0402; 0402-cap
C190, C193: C_18p_0402; 0402-cap
D1, D5, D6, D7, D8, D9, D10: KP-1608CGCK; LED_0603
D2, D11: PDS760-13
D3: TPD2E009; SOT-3
D4: TPD6E05U06
FB1, FB2, FB3, FB7: BLM18PG121SN1D; 0603-res
FB4, FB5, FB6: BLM18AG601SN1D; 0603
IC1: TPS54561; WSON-10_4x4
IC3: TPD8S009DSMR; R-PDSO-N15
J1: 0878311420; PinHeader_2x7_P2mm_Drill1mm
J3: DC_SOCKET
J4: WE_629105150521; USB_Micro_B_Female_629105150521
J6: 685119134923; HDMI_A_Female_685119134923
J7: 1140084168; MicroSD_1140084168
J8, J10: 61300311121; PinHeader_1x3_P2.54_Drill1.1mm
J?1: WE-RJ45_7499111121A; 7499111121A
L1: IHLP2020BZER4R7M01
L2: DFE322512F-R68M=P2; INDC3225X120N
L3, L4, L5: IHLP1212AEERR47M11; IHLP-1212AE
L6: WE_7447798720
MODE2: 61300311121; PinHeader_1x3_P2.54_Drill1.1mm
N1: oshw_logo; oshw-logo
N2: antmicro_logo; antmicro-logo_scaled_20mm
PROG_B1: B3U-1000P; Switch_Tactile_SMD_B3U-1000P
PUDC_B1: test; Testpoint_smd_1mm
PWR1: KP-1608CGCK; LED_0603
Q2, Q3, Q4, Q5, Q6, Q7, Q8: BSS138APW; SC70-3
R1, R2, R3, R4, R5, R6, R7, R8, R18, R19, R20, R25, R37: R_22R_0402; 0402-res
R9, R11, R12, R13, R23, R24, R26, R27, R42, R55, R58, R59, R60, R82, R139, R140, R141, R142, R143, R144, R145, R146: R_0R_0402; 0402-res
R10, R33, R34, R36: R_100R_0402; 0402-res
R14, R77, R89, R90, R91, R92, R93, R94, R95, R96: R_2k2_0402; 0402-res
R15, R16, R17, R21, R22, R28, R29, R32: R_4k7_0402; 0402-res
R30, R31, R50, R51, R52, R53, R54, R57, R119: R_330R_0402; 0402-res
R35: R_5R1_0402; 0402-res
R38, R39, R41, R43, R44, R47, R85: R_0R_0603; 0603-res
R40, R83, R84, R122: R_100k_0402; 0402-res
R45: R_453k_0402; 0402-res
R46: R_100k_1%_0402; 0402
R48: R_66k5_0603; 0603-res
R49: R_100k_0603; 0603-res
R56, R61, R86, R87, R88, R130: R_10k_0402; 0402-res
R62, R67, R136: R_220R_0402; 0402-res
R68: R_12k1_0402; 0402-res
R69: R_1M8_0402; 0402-res
R70, R71, R72, R73, R74, R75, R76, R79, R80, R81, R128: R_10k2_0402; 0402-res
R78: R_1k_0402; 0402-res
R97, R98, R99, R100, R101, R102, R103, R104, R105, R106, R107, R108, R109, R110, R111, R112, R113, R114, R117, R118, R120, R121, R123, R124, R125, R147, R148, R149, R150, R151, R152, R153, R154, R155, R156, R157: R_0R_0201; 0201-res
R115: R_16k9_0402; 0402-res
R116: R_243k_0402; 0402-res
R126: R_49R9_0402; 0402-res
R127: R_53k6_0402; 0402-res
R129: R_12k_0402; 0402-res
R131, R132, R133, R134, R135, R137, R138: R_20k_0402; 0402-res
S1: EG1218; Switch_Slide_11.6x4mm_EG1218
TP1, TP2, TP3, TP4, TP5, TP6, TP7, TP8, TP9: TP_SMD1MM; Testpoint_smd_1mm
U3: S25FL128SAGNFI000
U4: TPS65296; VQFN-HR
U5, U9, U12: TPS62823DLCT; QFN-8_2x1mm
U6: KSZ9031RNXCA; QFN-48-Microchip-QFN77-48LD-PL-2
U7: FT4232HQ
U8: SRST; Testpoint_smd_1mm
U10: LM3881MME_NOPB; VSSOP8-Texas_Instruments-DGK0008A
U11: S27KL0641DABHI023; FBGA-24
U14: 2199155-1
U15: XC7K160T-FFG676; BGA676C100P26X26_2700X2700X254
USR_BTN1, USR_BTN2, USR_BTN3, USR_BTN4: B3U-1000P; Switch_Tactile_SMD_B3U-1000P
Y1: ABM8G-25.000MHZ-18-D2Y-T; KX-7
Y2: ABM8G-12.000MHZ-18-D2Y-T; KX-7

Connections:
1V0_SYS: C20.1, C26.1, R47.1, U15.J9, U15.K8, U15.K10, U15.K12, U15.K14, U15.L9, U15.L13, U15.L15, U15.M8, U15.M14, U15.N9, U15.N13, U15.N15, U15.P14, U15.R13, U15.R15, U15.T12, U15.T14, U15.U13, U15.U15
1V1_SYS: J10.1, R38.2
1V8_FT: C195.1, C196.1, C197.1, C198.1, U7.12, U7.37, U7.49, U7.64
1V8_SYS: R39.2, U15.E8, U15.L11, U15.M10, U15.M12, U15.P10, U15.T10, U15.U11
3V3_SYS: 3V3.1, C5.1, C10.1, C46.1, C102.1, C103.1, C104.1, C105.1, C123.1, C127.1, C131.1, C136.1, C139.1, C186.1, C188.1, C191.1, C192.1, C194.1, D1.1, D5.1, D6.1, D7.1, D8.1, D9.1, D10.1, FB1.1, FB4.1, FB5.1, IC3.13, IC3.15, J1.2, J7.4, MODE2.3, PWR1.1, R9.2, R10.1, R12.2, R14.2, R15.1, R16.1, R17.1, R21.1, R22.1, R28.1, R29.1, R32.1, R33.1, R44.1, R56.1, R57.1, R58.1, R61.1, R62.2, R67.2, R70.2, R71.2, R72.2, R73.2, R74.2, R75.2, R76.2, R78.2, R79.2, R80.2, R81.2, R130.1, R131.1, R132.1, R133.1, R134.1, R135.1, R137.1, R138.1, U3.8, U6.16, U6.34, U6.40, U7.20, U7.31, U7.42, U7.50, U7.56, U11.B4, U11.D1, U11.E4, U15.A11, U15.A21, U15.AA21, U15.AC25, U15.AD22, U15.AF26, U15.B8, U15.C25, U15.D12, U15.D22, U15.E9, U15.F26, U15.G13, U15.G23, U15.H10, U15.L7, U15.L21, U15.T6, U15.U23, U15.V20, U15.Y24
12V: U14.1, U14.145
/Ethernet/AVDDH: C132.1, C137.1, C140.1, FB1.2, U6.1, U6.12
/Ethernet/AVDDL: C121.1, C125.1, C129.1, C134.1, FB3.1, U6.4, U6.9
/Ethernet/AVDDL_PLL: C124.1, C128.1, C133.1, FB2.1, U6.44
/Ethernet/ETH1_N: J?1.2, U6.3
/Ethernet/ETH1_P: J?1.1, U6.2
/Ethernet/ETH2_N: J?1.6, U6.6
/Ethernet/ETH2_P: J?1.3, U6.5
/Ethernet/ETH3_N: J?1.5, U6.8
/Ethernet/ETH3_P: J?1.4, U6.7
/Ethernet/ETH4_N: J?1.8, U6.11
/Ethernet/ETH4_P: J?1.7, U6.10
/Supply/SYS_EN: IC1.3, S1.2, TP9.1
/Supply/VCC_AUX_EN: R87.2, TP7.1, U4.11, U10.7
/Supply/VCC_INT_EN: R86.2, TP6.1, U9.1, U10.8
/Supply/VCC_IO_EN: R82.2, R88.2, TP8.1, U4.10, U5.1, U10.6
A0: U14.79, U15.V12
A1: U14.72, U15.AC11
A2: U14.216, U15.AD11
A3: U14.71, U15.AD10
A4: U14.214, U15.AC9
A5: U14.213, U15.AD9
A6: U14.69, U15.AB9
A7: U14.211, U15.AF7
A8: U14.68, U15.AE8
A9: U14.66, U15.AE7
A10\AP: U14.225, U15.Y12
A11: U14.210, U15.AC7
A12\~BC: U14.65, U15.AB7
A13: U14.232, U15.AD13
A17: U14.234, U15.AC13
AUX_JTAG_TCK: R1.2, U15.C24
AUX_JTAG_TDI: R2.2, U15.D24
AUX_JTAG_TDO: R3.2, U15.C26
AUX_JTAG_TMS: R4.2, U15.D25
BA0: U14.81, U15.AB11
BA1: U14.224, U15.AB10
BG0: U14.63, U15.AA9
BG1: U14.207, U15.AF9
CB0: U14.49, U15.AF3
CB1: U14.194, U15.AE5
CB2: U14.56, U15.AD6
CB3: U14.201, U15.AC6
CB4: U14.47, U15.AF2
CB5: U14.192, U15.AE3
CB6: U14.54, U15.AE6
CB7: U14.199, U15.AD5
CCLK: R24.2, R33.2, R34.1, U15.C8
CFGBVS: R58.2, U15.P7
CK0_C: U14.75, U15.AF12
CK0_T: U14.74, U15.AE12
CK1_C: U14.219, U15.AB12
CK1_T: U14.218, U15.AC12
CKE0: U14.60, U15.AA8
CKE1\NC: U14.203, U15.AA7
C_TMDS_CLK_N: IC3.12, J6.12, R139.2
C_TMDS_CLK_P: IC3.10, J6.10, R140.2
C_TMDS_D0_N: IC3.9, J6.9, R141.2
C_TMDS_D0_P: IC3.7, J6.7, R142.2
C_TMDS_D1_N: IC3.6, J6.6, R143.2
C_TMDS_D1_P: IC3.4, J6.4, R144.2
C_TMDS_D2_N: IC3.3, J6.3, R145.2
C_TMDS_D2_P: IC3.1, J6.1, R146.2
DBG_USB_N: D3.1, J4.2, U7.7
DBG_USB_P: D3.2, J4.3, U7.8
DONE: Q7.1, R57.2, U15.J7
DQ0: U14.5, U15.W11
DQ1: U14.150, U15.Y11
DQ2: U14.12, U15.V7
DQ3: U14.157, U15.Y7
DQ4: U14.3, U15.V11
DQ5: U14.148, U15.V9
DQ6: U14.10, U15.V8
DQ7: U14.155, U15.W8
DQ8: U14.16, U15.U2
DQ9: U14.161, U15.V6
DQ10: U14.23, U15.Y2
DQ11: U14.168, U15.Y3
DQ12: U14.14, U15.U5
DQ13: U14.159, U15.U4
DQ14: U14.21, U15.W3
DQ15: U14.166, U15.Y1
DQ16: U14.27, U15.AA2
DQ17: U14.172, U15.AB2
DQ18: U14.34, U15.AE1
DQ19: U14.179, U15.AE2
DQ20: U14.25, U15.V2
DQ21: U14.170, U15.W1
DQ22: U14.32, U15.AD1
DQ23: U14.177, U15.AC2
DQ24: U14.38, U15.W4
DQ25: U14.183, U15.AA3
DQ26: U14.45, U15.AD3
DQ27: U14.190, U15.AC4
DQ28: U14.36, U15.V3
DQ29: U14.181, U15.V4
DQ30: U14.43, U15.AB4
DQ31: U14.188, U15.AC3
DQ32: U14.97, U15.AC16
DQ33: U14.242, U15.AC17
DQ34: U14.104, U15.AB16
DQ35: U14.249, U15.AA19
DQ36: U14.95, U15.AB15
DQ37: U14.240, U15.AD16
DQ38: U14.102, U15.AC18
DQ39: U14.247, U15.AC19
DQ40: U14.108, U15.AF17
DQ41: U14.253, U15.AE17
DQ42: U14.115, U15.AF20
DQ43: U14.260, U15.AD19
DQ44: U14.106, U15.AE15
DQ45: U14.251, U15.AE16
DQ46: U14.113, U15.AF19
DQ47: U14.258, U15.AD18
DQ48: U14.119, U15.Y18
DQ49: U14.264, U15.Y17
DQ50: U14.126, U15.W14
DQ51: U14.271, U15.V14
DQ52: U14.117, U15.AA20
DQ53: U14.262, U15.AA15
DQ54: U14.124, U15.V18
DQ55: U14.269, U15.W16
DQ56: U14.130, U15.AA18
DQ57: U14.275, U15.AB19
DQ58: U14.137, U15.V16
DQ59: U14.282, U15.W15
DQ60: U14.128, U15.AB17
DQ61: U14.273, U15.AA17
DQ62: U14.135, U15.V19
DQ63: U14.280, U15.V17
DQS0_C: R98.2, U14.152, U15.W9
DQS0_T: R97.2, U14.153, U15.W10
DQS1_C: R100.2, U14.163, U15.W5
DQS1_T: R99.2, U14.164, U15.W6
DQS2_C: R102.2, U14.174, U15.AC1
DQS2_T: R101.2, U14.175, U15.AB1
DQS3_C: R104.2, U14.185, U15.AB5
DQS3_T: R103.2, U14.186, U15.AA5
DQS4_C: R106.2, U14.244, U15.AE20
DQS4_T: R105.2, U14.245, U15.AD20
DQS5_C: R108.2, U14.255, U15.AF18
DQS5_T: R107.2, U14.256, U15.AE18
DQS6_C: R110.2, U14.266, U15.W19
DQS6_T: R109.2, U14.267, U15.W18
DQS7_C: R112.2, U14.277, U15.Y16
DQS7_T: R111.2, U14.278, U15.Y15
DQS8_C: R114.2, U14.196, U15.AF4
DQS8_T: R113.2, U14.197, U15.AF5
DQS9_C: R98.1, R149.2, U14.8
DQS9_T: R97.1, R148.2, U14.7
DQS10_C: R100.1, R153.2, U14.19
DQS10_T: R99.1, R152.2, U14.18
DQS11_C: R102.1, R155.2, U14.30
DQS11_T: R101.1, R154.2, U14.29
DQS12_C: R104.1, R151.2, U14.41
DQS12_T: R103.1, R150.2, U14.40
DQS13_C: R106.1, R124.2, U14.100
DQS13_T: R105.1, R123.2, U14.99
DQS14_C: R108.1, R121.2, U14.111
DQS14_T: R107.1, R120.2, U14.110
DQS15_C: R110.1, R147.2, U14.122
DQS15_T: R109.1, R125.2, U14.121
DQS16_C: R112.1, R118.2, U14.133
DQS16_T: R111.1, R117.2, U14.132
DQS17_C: R114.1, R157.1, U14.52
DQS17_T: R113.1, R156.1, U14.51
ETH_INT_N: U6.38, U15.Y20
ETH_MDC: U6.36, U15.AA25
ETH_MDIO: R78.1, U6.37, U15.AB26
ETH_REF_CLK: R76.1, R94.1, U6.41, U15.AA23
ETH_RSTN: R79.1, U6.42, U15.AA22
ETH_RXD0: R70.1, R77.1, U6.32, U15.W26
ETH_RXD1: R71.1, R89.1, U6.31, U15.W25
ETH_RXD2: R72.1, R90.1, U6.28, U15.V26
ETH_RXD3: R73.1, R91.1, U6.27, U15.U25
ETH_RX_CLK: R75.1, R93.1, U6.35, U15.Y23
ETH_RX_DV: R74.1, R92.1, U6.33, U15.Y25
ETH_TXD0: U6.19, U15.W24
ETH_TXD1: U6.20, U15.Y26
ETH_TXD2: U6.21, U15.Y22
ETH_TXD3: U6.22, U15.Y21
ETH_TX_CLK: U6.24, U15.AA24
ETH_TX_EN: U6.25, U15.U26
FCS_B: R14.1, R23.2, U15.C23
GND: C1.2, C2.2, C4.2, C5.2, C10.2, C20.2, C26.2, C27.2, C28.2, C29.2, C30.2, C31.2, C33.2, C36.2, C37.2, C38.2, C39.2, C40.2, C41.2, C42.2, C46.2, C96.2, C97.2, C99.2, C100.1, C101.2, C102.2, C103.2, C104.2, C105.2, C109.2, C116.2, C117.2, C118.2, C119.2, C120.2, C121.2, C122.2, C123.2, C124.2, C125.2, C126.2, C127.2, C128.2, C129.2, C130.2, C131.2, C132.2, C133.2, C134.2, C135.2, C136.2, C137.2, C138.2, C139.2, C140.2, C141.2, C142.2, C147.2, C148.2, C149.2, C151.2, C152.2, C172.2, C174.2, C175.2, C180.2, C182.2, C183.2, C184.2, C185.2, C186.2, C187.2, C188.2, C189.2, C190.2, C191.2, C192.2, C193.2, C194.2, C195.2, C196.2, C197.2, C198.2, D2.A, D3.3, D4.5, D4.10, FB6.1, FB7.2, IC1.8, IC1.11, IC3.2, IC3.5, IC3.8, IC3.11, J1.1, J1.3, J1.5, J1.7, J1.9, J1.11, J1.13, J3.2, J3.3, J4.5, J6.2, J6.5, J6.8, J6.11, J6.17, J6.SH, J7.6, J7.10, J7.~, J8.3, J?1.10, MODE2.1, PROG_B1.2, Q2.2, Q3.2, Q4.2, Q5.2, Q6.2, Q7.2, Q8.2, R11.2, R13.2, R34.2, R36.2, R46.2, R49.2, R55.2, R68.1, R77.2, R84.2, R89.2, R90.2, R91.2, R92.2, R93.2, R94.2, R95.2, R96.2, R116.1, R119.2, R128.2, R129.1, S1.3, U3.4, U4.3, U4.9, U4.16, U5.3, U5.5, U6.29, U6.49, U7.1, U7.5, U7.11, U7.13, U7.15, U7.25, U7.35, U7.47, U7.51, U7.65, U9.3, U9.5, U10.3, U11.B3, U11.C1, U11.E5, U12.3, U12.5, U15.A1, U15.A2, U15.A5, U15.A6, U15.A7, U15.A16, U15.A26, U15.AA6, U15.AA16, U15.AA26, U15.AB3, U15.AB13, U15.AB23, U15.AC10, U15.AC20, U15.AD7, U15.AD17, U15.AE4, U15.AE14, U15.AE24, U15.AF1, U15.AF11, U15.AF21, U15.B4, U15.B7, U15.B13, U15.B23, U15.C1, U15.C5, U15.C7, U15.C10, U15.C20, U15.D4, U15.D7, U15.D17, U15.E1, U15.E2, U15.E5, U15.E7, U15.E14, U15.E24, U15.F3, U15.F4, U15.F7, U15.F11, U15.F21, U15.G1, U15.G5, U15.G8, U15.G18, U15.H4, U15.H7, U15.H15, U15.H25, U15.J1, U15.J2, U15.J5, U15.J12, U15.J22, U15.K3, U15.K4, U15.K7, U15.K9, U15.K11, U15.K13, U15.K19, U15.L1, U15.L5, U15.L10, U15.L12, U15.L14, U15.L16, U15.L26, U15.M4, U15.M7, U15.M9, U15.M11, U15.M13, U15.M15, U15.M23, U15.N1, U15.N2, U15.N5, U15.N7, U15.N10, U15.N11, U15.N12, U15.N14, U15.N20, U15.P3, U15.P4, U15.P9, U15.P11, U15.P12, U15.P13, U15.P15, U15.P17, U15.R1, U15.R2, U15.R5, U15.R8, U15.R10, U15.R11, U15.R12, U15.R14, U15.R24, U15.T1, U15.T3, U15.T4, U15.T9, U15.T11, U15.T13, U15.T15, U15.T21, U15.U8, U15.U10, U15.U12, U15.U14, U15.U18, U15.V5, U15.V15, U15.V25, U15.W2, U15.W12, U15.W22, U15.Y9, U15.Y19, USR_BTN1.2, USR_BTN2.2, USR_BTN3.2, USR_BTN4.2, Y1.2, Y1.4, Y2.2, Y2.4
HR_CKN: U11.B1, U15.AE26
HR_CKP: U11.B2, U15.AD26
HR_CS: R61.2, U11.A3, U15.AC26
HR_DQ0: U11.D3, U15.AE23
HR_DQ1: U11.D2, U15.AD25
HR_DQ2: U11.C4, U15.AF24
HR_DQ3: U11.D4, U15.AE22
HR_DQ4: U11.D5, U15.AF23
HR_DQ5: U11.E3, U15.AF25
HR_DQ6: U11.E2, U15.AE25
HR_DQ7: U11.E1, U15.AD24
HR_RST: R56.2, U11.A4, U15.AC24
HR_RW: U11.C3, U15.AD23
INIT_B: Q8.1, R28.2, U15.G7
LED_LINK: J?1.12, R81.1, R96.1, U6.17
LED_SPD: J?1.14, R80.1, R95.1, U6.15
MODE0: R9.1, R11.1, U15.T5
MODE1: R12.1, R13.1, U15.T2
MODE2: MODE2.2, U15.P5
NC\C2: U14.235, U15.AD14
unnamed: C35.1, L2.1, U4.17
unnamed: C35.2, R35.2
unnamed: C36.1, U4.6
unnamed: C38.1, R41.1, R42.2, U4.2
unnamed: C45.1, L3.2, R44.2, R45.1
unnamed: C45.2, R45.2, R46.1, U5.2
unnamed: C96.1, C98.1, C99.1, L4.2, R47.2, R48.1
unnamed: C98.2, R48.2, R49.1, U9.2
unnamed: C100.2, U10.5
unnamed: C147.1, R69.1, U6.45, Y1.1
unnamed: C148.1, R69.2, U6.46, Y1.3
unnamed: C150.1, C151.1, C152.1, L5.2, R83.1, R85.2
unnamed: C150.2, R83.2, R84.1, U12.2
unnamed: C172.1, R115.2
unnamed: C174.1, IC1.4
unnamed: C175.1, IC1.7, R115.1
unnamed: C178.1, D2.C, IC1.9, L6.1
unnamed: C178.2, IC1.1
unnamed: C184.1, C187.1, FB4.2, U7.9
unnamed: C185.1, C189.1, FB5.2, U7.4
unnamed: C190.1, U7.2, Y2.1
unnamed: C193.1, U7.3, Y2.3
unnamed: D1.2, R30.1
unnamed: D5.2, R50.1
unnamed: D6.2, R51.1
unnamed: D7.2, R52.1
unnamed: D8.2, R53.1
unnamed: D9.2, R54.1
unnamed: D10.2, R31.1
unnamed: D11.A, J3.1
unnamed: FB6.2, J4.6
unnamed: FB7.1, J?1.Z1, J?1.Z2
unnamed: IC1.5, R116.2
unnamed: IC1.6, R127.2, R128.1
unnamed: J6.13, TP1.1
unnamed: J6.15, TP2.1
unnamed: J6.16, TP4.1
unnamed: J6.18, TP5.1
unnamed: J6.19, TP3.1
unnamed: J7.9, R136.2
unnamed: J?1.11, R62.1
unnamed: J?1.13, R67.1
unnamed: L1.1, U4.15
unnamed: L3.1, U5.6
unnamed: L4.1, U9.6
unnamed: L5.1, U12.6
unnamed: PWR1.2, R119.1
unnamed: Q2.3, R50.2
unnamed: Q3.3, R51.2
unnamed: Q4.3, R52.2
unnamed: Q5.3, R53.2
unnamed: Q6.3, R54.2
unnamed: Q7.3, R30.2
unnamed: Q8.3, R31.2
unnamed: R1.1, U7.26
unnamed: R2.1, U7.27
unnamed: R3.1, U7.28
unnamed: R4.1, U7.29
unnamed: R5.1, U7.32
unnamed: R6.1, U7.38
unnamed: R7.1, U7.39
unnamed: R8.1, U7.48
unnamed: R18.1, U7.16
unnamed: R19.1, U7.17
unnamed: R20.1, U7.18
unnamed: R23.1, U3.1
unnamed: R24.1, U3.6
unnamed: R25.1, U7.19
unnamed: R26.1, U3.7
unnamed: R27.1, U3.3
unnamed: R35.1, U4.18
unnamed: R37.1, U7.52
unnamed: R40.1, U4.8
unnamed: R42.1, U4.4
unnamed: R55.1, U10.4
unnamed: R59.1, U3.5
unnamed: R60.1, U3.2
unnamed: R68.2, U6.48
unnamed: R82.1, U12.1
unnamed: R117.1, U15.M25
unnamed: R118.1, U15.L25
unnamed: R120.1, U15.P19
unnamed: R121.1, U15.P20
unnamed: R123.1, U15.T24
unnamed: R124.1, U15.T25
unnamed: R125.1, U15.R16
unnamed: R126.2, R127.1
unnamed: R129.2, U7.6
unnamed: R130.2, U7.14
unnamed: R147.1, U15.R17
unnamed: R148.1, U15.B17
unnamed: R149.1, U15.A17
unnamed: R150.1, U15.J15
unnamed: R151.1, U15.J16
unnamed: R152.1, U15.D19
unnamed: R153.1, U15.D20
unnamed: R154.1, U15.L19
unnamed: R155.1, U15.L20
unnamed: R156.2, U15.AC8
unnamed: R157.2, U15.AD8
unnamed: U7.22, U8.1
ODT0: U14.87, U15.Y13
ODT1\NC: U14.91, U15.AB14
PARITY: U14.222, U15.AE13
PROGRAM_B: PROG_B1.1, R32.2, U15.P6
PUDC_B: PUDC_B1.1, R10.2, R36.1, U15.B25
QSPI_DQ0: R59.2, U15.B24
QSPI_DQ1: R60.2, U15.A25
QSPI_DQ2: R22.2, R27.2, U15.B22
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

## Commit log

2021-06-24 Initial commit - add design files from LPDDR4 board
    [config-spi.sch, ddr4-datacenter-tester.sch, ethernet.sch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]
2021-08-19 Change board outline, import DIMM connector and FPGA to PCB
    [config-spi.sch, ddr4-datacenter-tester.sch, ethernet.sch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]
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2021-08-19 Add DD4 pinout, connect ethernet, QSPI, TMDS, SDIO
    [DDR4.sch, config-spi.sch, ddr4-datacenter-tester.kicad_pcb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]
2021-08-19 Connect QSPI (fix), GPIOs, JTAG, HR, UART
    [ddr4-datacenter-tester.kicad_pcb, fpga-banks-12-15.sch, fpga-banks-16-34.sch]
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2021-08-19 ADD DDR4 connection to FPGA and signals routing - WIP
    [DDR4.sch, ddr4-datacenter-tester.kicad_pcb, fpga-banks-16-34.sch]
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2021-08-19 Fix PDF schematic
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2021-08-23 Update pinout
    Add testpad and DNP 0R at 12V dedicated for NVRDIMM
    [DDR4.sch]
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2021-09-29 Replace 0R power supply resistors with fuses
    [supply.sch]
2021-10-21 Fix CKO and CK1 signalls
    [DDR4.sch, fpga-banks-16-34.sch]
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2021-10-21 Add labels to DQS[9:17] and route them as differential pairs
    [fpga-banks-12-15.sch, fpga-banks-16-34.sch]
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2022-03-03 Connect RDIMM pins 206,209,212,215,217,220 to VDDQ instead of GND
    [DDR4.sch]
2022-03-03 Bump the revision to 1.1.0, Update layout, DRC-clean
    [DDR4.sch, config-spi.sch, data-center-dram-tester.sch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]
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2022-03-04 Fix VDDQ capacitors
    [DDR4.sch]
2022-03-04 Add missing 3D models
    [config-spi.sch, supply.sch]
2022-03-14 Replace R41 with 200k #32496
    [supply.sch]
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2022-03-18 Replace R159 and R161 with ferrite beads #32498
    [supply.sch]
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2022-04-14 Change TPS62823DLCT to MP2162BGQH. Apply changes to PCB
    [supply.sch]
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2022-08-12 Migrate the project to KiCad 6, fix U8 EN-GND cross, bumped revision to 1.1.2
    [DDR4.kicad_sch, DDR4.sch, config-spi.kicad_sch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]
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2022-09-06 Add PoE circuitry to PCB. Move Ethernet, uSD, power switch and memory to the side. Fix broken traces
2022-09-06 Fix finish layout of the PoE, fix Ethernet traces
2022-09-06 Fix MicroSD_1140084168 symbol and footprint issue
    [ethernet.kicad_sch, interfaces.kicad_sch]
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2022-09-08 Change PoE controller to TPS2373-4RGWR and update placement on PCB
    [data-center-dram-tester.kicad_sch, ethernet.kicad_sch, supply.kicad_sch]
2022-09-09 Finish layout with new PoE controller. DRC and silks clearing
    [data-center-dram-tester.kicad_sch, ethernet.kicad_sch]
2022-09-14 Replace PoE IC to TPS2372-3RGWR with improved footprint
    [data-center-dram-tester.kicad_sch, ethernet.kicad_sch]
2022-09-14 Added PCIe sheet, initial connection of the PCIe interface
    [data-center-dram-tester.kicad_sch, fpga-power.kicad_sch, pcie.kicad_sch]
2022-09-19 For PCIe: added MGTAVTT calibration resistor, proper HCSL temination, REFCLK AC decoupling, PERST connection, corrected PRSNT1 to PRSNT2 connection.
    [data-center-dram-tester.kicad_sch, pcie.kicad_sch]
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2022-09-21 Change shunt resistors to 10mOhm on VPP, VTT, 5V0, 3V3, 1V8 and 1V0 rails
    [data-center-dram-tester.kicad_sch, supply.kicad_sch]
2022-09-21 Added VTT_CNTL and SLP_S4 FPGA Control for Hot Swap
    [data-center-dram-tester.kicad_sch, supply.kicad_sch]
2022-09-22 Added hot-swap: button, LED indication, detection on ground pin. Updated SN74LVC1G07 symbol
    [DDR4.kicad_sch, data-center-dram-tester.kicad_sch, interfaces.kicad_sch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]
2022-09-23 B2B FMC HPC connector added, recconected PCIe to new connector, added ETH mux
    [data-center-dram-tester.kicad_sch, ethernet.kicad_sch, fmc_hpc.kicad_sch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]
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2022-09-26 Connect ETH mux, connect AUX_JTAG to FMC connector, add RC filter for HOT_SWAP_BUTTON signal
    [DDR4.kicad_sch, data-center-dram-tester.kicad_sch, ethernet.kicad_sch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]
2022-09-27 Replaced JTAG to surface mount, Update FMC HPC socket
    [data-center-dram-tester.kicad_sch, fmc_hpc.kicad_sch]
2022-09-27 Reconnect FMC signals to new socket, and JTAG to new connector
    [config-spi.kicad_sch, data-center-dram-tester.kicad_sch, fmc_hpc.kicad_sch]
2022-09-28 Replace MODE2 jumpers with SMD DIP switch. Replace power cycle,VTT_CNTL and SLP_S4 ccircuits with tri-state buffer ones. Add possibilty to swith ETH paths with FPGA
    [config-spi.kicad_sch, data-center-dram-tester.kicad_sch, ethernet.kicad_sch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]
2022-09-29 Re-add mounting holes, add tri-state buffer for FPGA_POWER_CYCLE signal
    [data-center-dram-tester.kicad_sch, supply.kicad_sch]
2022-09-30 Correct PCIe pin assigment, replace MODE2 symbol, export changes to PCB, progess in the new components placement
    [config-spi.kicad_sch, data-center-dram-tester.kicad_sch, ethernet.kicad_sch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]
2022-10-03 All components inside the board area, fix FMC column B shift on schematic, add PCIe layer dependent rules
    [fmc_hpc.kicad_sch, supply.kicad_sch]
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2022-10-07 Propose optimized DDR4 pinout for die[6..9], initial BGA fanout for bank 32
    [fpga-banks-16-34.kicad_sch]
2022-10-10 Update FPGA symbol (die to pad length), initial fanout for die [1..4]
    [config-spi.kicad_sch, data-center-dram-tester.kicad_sch, fpga-banks-12-15.kicad_sch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]
2022-10-11 Add new pinout for bank 32 and 34, create custom DRC rules for DDR, initial routing for die 6,7,9
    [data-center-dram-tester.kicad_sch, fpga-banks-12-15.kicad_sch, fpga-banks-16-34.kicad_sch]
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2022-10-13 Finish assigning address, command and control pins. Finish initial rerouting of DDR4 interface
    [fpga-banks-12-15.kicad_sch, fpga-banks-16-34.kicad_sch]
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2022-10-17 Route internal end external (FMC) ETH interface, add additional VDDQ and ETH MUX decoupling
    [data-center-dram-tester.kicad_sch, ethernet.kicad_sch, fpga-power.kicad_sch]
2022-10-18 Add ETH MUX passthrough, reroute HDMI to 100 Ohm differential, begin routing current measurment circuit
    [data-center-dram-tester.kicad_sch, ethernet.kicad_sch, fpga-power.kicad_sch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]
2022-10-19 Add kelvin connection to shunt resistors, move some data, control and address traces from layer In.9 to In.5, route current measurment circuit
    [data-center-dram-tester.kicad_sch, supply.kicad_sch]
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2022-10-21 Implement LED and PB mechanical concept. Assign bank 15 to FMC, remove buttons and add new ones
    [config-spi.kicad_sch, data-center-dram-tester.kicad_sch, fpga-banks-12-15.kicad_sch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]
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2022-10-25 Finish mechanical concept, add active capacitor discharge circuit for all AP DC-DC, add pushbutton controler circuit
    [data-center-dram-tester.kicad_sch, interfaces.kicad_sch, supply.kicad_sch]
2022-10-25 Fix BZX84C5V1-TP footprint assigment
2022-10-26 Assign and fanout on FPGA and FMC for bank 15 signals
    [data-center-dram-tester.kicad_sch, fmc_hpc.kicad_sch, supply.kicad_sch]
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2022-10-28 Finish routing FMC, start routing remainig misc signals
    [fmc_hpc.kicad_sch, supply.kicad_sch]
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2022-10-31 Replace visualisation in README and schematic
    [data-center-dram-tester.kicad_sch, pcie.kicad_sch]
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2022-11-02 Add missing FMC vias, route: MODE, JTAG, active discharge, reconnect 5V buses
    [data-center-dram-tester.kicad_sch, ethernet.kicad_sch, fpga-banks-12-15.kicad_sch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]
2022-11-03 Assign and connect misc. signals. Add, place and route decoupling capacitors
    [data-center-dram-tester.kicad_sch, fmc_hpc.kicad_sch, fpga-banks-12-15.kicad_sch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]
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2022-11-08 Length match and deskew Die 7, Die3, command, control and addres. Modify SPI Flash footprint
    [config-spi.kicad_sch, data-center-dram-tester.kicad_sch]
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2022-11-09 replace 120R VRN, VRP resistors with 80.6R ones
    [data-center-dram-tester.kicad_sch, fpga-banks-16-34.kicad_sch]
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2022-11-14 Progress in HS matching and deskewing, clear DRC, implement schematic review changes, SI improvments
    [data-center-dram-tester.kicad_sch, fpga-banks-16-34.kicad_sch, interfaces.kicad_sch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]
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2022-11-22 Fix the remark
    [supply.kicad_sch]
2022-11-22 DDR SI improvments, optimize bom, apply review issues fix
    [data-center-dram-tester.kicad_sch, ethernet.kicad_sch, interfaces.kicad_sch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]
2022-11-23 Optimize BOM, add all bank 115 and 116 REFCLK's to FMC connector
    [config-spi.kicad_sch, data-center-dram-tester.kicad_sch, fmc_hpc.kicad_sch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]
2022-11-25 Implement all review fixes, route control signals from FMC to FPGA
    [DDR4.kicad_sch, config-spi.kicad_sch, data-center-dram-tester.kicad_sch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]
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2022-11-28 Fix SD card reference plane, minor polygon adjustment, fix PoE clereance, fix net class assigment
    [DDR4.kicad_sch, config-spi.kicad_sch, data-center-dram-tester.kicad_sch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]
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2022-12-01 Silkscreen adjustment, add PCB SHA, add missing 3D models
    [data-center-dram-tester.kicad_sch, fpga-power.kicad_sch, supply.kicad_sch]
2022-12-02 Fix hidden silkscreen
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2023-03-24 Add missing ON/OFF controller pull-ups, add possibility for instant turn off
    [data-center-dram-tester.kicad_sch, supply.kicad_sch]
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2023-03-24 Apply fixes to PCB
    [ethernet.kicad_sch]
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2023-03-24 Add updated visualisation, fix date
    [DDR4.kicad_sch, config-spi.kicad_sch, data-center-dram-tester.kicad_sch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]
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2023-03-27 Fix FPGA footprint
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

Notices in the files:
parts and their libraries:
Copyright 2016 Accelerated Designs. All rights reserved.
